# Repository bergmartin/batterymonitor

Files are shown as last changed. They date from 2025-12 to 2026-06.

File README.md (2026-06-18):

# ESP32 Battery Voltage Monitor

A PlatformIO project for monitoring 12V battery voltage using an ESP32 microcontroller with **ultra-low power consumption** through deep sleep mode.

## 🌟 Key Features

- **Ultra-Low Power:** Deep sleep mode with only 0.12-0.23 mA average draw (99.8% power reduction!)
- **Long Battery Life:** Monitor can run for years on the battery it's monitoring
- **MQTT Integration:** Publish readings to MQTT broker for remote monitoring (Home Assistant, Node-RED, etc.)
- **OLED Display:** SH1106 128x64 display shows battery voltage, percentage, status, and WiFi signal strength
- Real-time 12V battery voltage monitoring
- Support for **Lead-Acid** and **LiFePO4** battery types
- Battery type configured at build time
- Battery percentage calculation with type-specific thresholds
- Battery status indicators (FULL, GOOD, LOW_BATTERY, CRITICAL, DEAD)
- Visual battery level display with progress bar
- WiFi signal strength indicator
- Low battery warnings
- Averaged ADC readings for accuracy
- RTC memory for persistent data across sleep cycles
- **3D Printable Enclosure** for professional deployment

## ⚡ Power Consumption

| Mode | Current Draw | Battery Life (100Ah) |
|---|---|---|
| **Deep Sleep (default)** | 0.12-0.23 mA | **50-95 years** 🎉 |
| Continuous monitoring | 80-160 mA | 26-52 days |

**Deep sleep mode draws less power than the battery loses naturally!**

See [DEEP_SLEEP.md](doc/DEEP_SLEEP.md) for detailed power analysis.

## Hardware Requirements

### Components
- ESP32 development board
- 12V battery
- 100kΩ resistor (R1)
- 22kΩ resistor (R2)
- SH1106 OLED Display (128x64, I2C) - optional but recommended
- Connecting wires

### Circuit Diagram

```
12V Battery (+) ----[100kΩ]----+----[22kΩ]---- GND
                               |
                          GPIO34 (ADC)
                          ESP32
```

### Voltage Divider Explanation

The ESP32 ADC can only read voltages up to 3.3V. To safely measure a 12V battery (and up to 14.6V for LiFePO4), we use a voltage divider:

- **R1** (100kΩ) + **R2** (22kΩ) creates a 5.55:1 ratio
- 12V battery voltage becomes ~2.16V at the ADC pin
- Formula: `V_ADC = V_Battery × (R2 / (R1 + R2))`
- Result: `V_ADC = 12V × (22kΩ / 122kΩ) = 2.16V`

## Wiring Instructions

1. **Connect Voltage Divider:**
   - Solder 100kΩ resistor (R1) to battery positive terminal
   - Connect 22kΩ resistor (R2) between the junction and GND
   - Connect junction point to GPIO34 on ESP32

2. **Ground Connection:**
   - Connect battery negative terminal to ESP32 GND

3. **Power ESP32:**
   - Power the ESP32 via USB or separate power supply
   - **Important:** Do NOT power ESP32 directly from the 12V battery without a voltage regulator

## Software Setup

### Installation

1. Install [PlatformIO](https://platformio.org/)
2. Clone or download this project
3. Open the project in VS Code with PlatformIO extension

### MQTT Configuration (Optional)

To enable remote monitoring via MQTT:

1. **Configure WiFi credentials:**
   ```bash
   cd include/
   cp wifi_credentials.h.example wifi_credentials.h
   # Edit wifi_credentials.h with your WiFi SSID and password
   ```

2. **Configure MQTT broker:**
   ```bash
   cp mqtt_credentials.h.example mqtt_credentials.h
   # Edit mqtt_credentials.h with your MQTT broker details
   ```

3. **See [MQTT.md](doc/MQTT.md) for complete MQTT setup guide**, including:
   - MQTT broker options (Mosquitto, CloudMQTT, Home Assistant)
   - Topic structure and JSON format
   - Home Assistant integration
   - Testing and troubleshooting

### Build and Upload

**Default (Lead-Acid battery):**
```bash
# Build the project
pio run

# Upload to ESP32
pio run --target upload

# Monitor serial output
pio device monitor
```

**For LiFePO4 battery:**
```bash
# Build for LiFePO4
pio run -e esp32dev -D BATTERY_TYPE=BATTERY_TYPE_LIFEPO4

# Upload to ESP32
pio run -e esp32dev -D BATTERY_TYPE=BATTERY_TYPE_LIFEPO4 --target upload

# Monitor serial output
pio device monitor
```

**Alternative: Edit platformio.ini**

Change the build flag in the default `[env:esp32dev]` section:
```ini
build_flags = 
  -D BATTERY_TYPE=BATTERY_TYPE_LIFEPO4  ; Options: BATTERY_TYPE_LEAD_ACID or BATTERY_TYPE_LIFEPO4
```

Or use PlatformIO IDE buttons in VS Code.

## Testing

The project includes comprehensive unit tests for all battery monitoring logic.

### Run Tests

**Test Lead-Acid configuration:**
```bash
pio test -e esp32dev
```

**Test LiFePO4 configuration:**
```bash
pio test -e esp32dev -D BATTERY_TYPE=BATTERY_TYPE_LIFEPO4
```

**Test both configurations:**
```bash
pio test
```

The tests cover:
- Battery percentage calculations
- Battery status determination
- ADC to voltage conversion
- Voltage divider safety
- Edge cases and boundary conditions

See `test/README.md` for detailed testing documentation.

## Configuration

### Battery Type Selection

The project supports two battery types, configured at **build time**:

**Option 1: Use the default environment with build flag**
- `esp32dev` with default `BATTERY_TYPE_LEAD_ACID` build flag
- `esp32dev` with `-D BATTERY_TYPE=BATTERY_TYPE_LIFEPO4` build flag for LiFePO4

**Option 2: Edit the default environment**

In `platformio.ini`, modify the build_flags:
```ini
[env:esp32dev]
build_flags = 
  -D BATTERY_TYPE=LEAD_ACID  ; or LIFEPO4
```

### Voltage Thresholds

The voltage thresholds are automatically set based on battery type:

**Lead-Acid (12V):**
- Full: 12.7V
- Nominal: 12.4V (75%)
- Low: 12.0V (25%)
- Critical: 11.8V
- Minimum: 10.5V

**LiFePO4 (12V nominal, 4S configuration):**
- Full: 14.6V
- Nominal: 13.2V (75%)
- Low: 12.8V (25%)
- Critical: 12.0V
- Minimum: 10.0V

### Other Adjustable Parameters

You can adjust these parameters in `lib/BatteryMonitor/battery_config.h` (in the `Config` namespace):

```cpp
constexpr int BATTERY_ADC_PIN = 34;           // ADC pin (GPIO34)
constexpr float VOLTAGE_DIVIDER_RATIO = 5.545;  // Adjust if using different resistors
constexpr unsigned long READING_INTERVAL_MS = 10000;  // Reading interval (active mode, 10 seconds)
constexpr uint64_t DEEP_SLEEP_INTERVAL_US = 3600000000ULL;  // Deep sleep interval (1 hour)
```

### For Different Resistor Values

If you use different resistors, calculate the voltage divider ratio:

```
VOLTAGE_DIVIDER_RATIO = (R1 + R2) / R2
```

Example:
- R1 = 100kΩ, R2 = 33kΩ → Ratio = 4.03
- R1 = 20kΩ, R2 = 10kΩ → Ratio = 3.0

## Serial Output Example

**Lead-Acid Battery:**
```
=================================
ESP32 Battery Voltage Monitor
=================================
Battery Type: Lead-Acid
Voltage Range: 10.5V - 12.7V

─────────────────────────────────
Battery Voltage: 12.45 V
Battery Level:   88.6 %
Status:          GOOD
Battery: [████████░░]
```

**LiFePO4 Battery:**
```
=================================
ESP32 Battery Voltage Monitor
=================================
Battery Type: LiFePO4
Voltage Range: 10.0V - 14.6V

─────────────────────────────────
Battery Voltage: 13.84 V
Battery Level:   83.5 %
Status:          GOOD
Battery: [████████░░]
```

## Battery Voltage Guidelines

The project automatically configures voltage thresholds based on your battery type selection.

### Lead-Acid Batteries (12V)
- **12.7V** - Fully charged (100%)
- **12.4V** - 75% charged
- **12.2V** - 50% charged
- **12.0V** - 25% charged
- **11.8V** - Discharged (should recharge)
- **10.5V** - Minimum safe voltage

### LiFePO4 Batteries (12V nominal, 4S configuration)
- **14.6V** - Fully charged (100%) - 4 × 3.65V
- **13.6V** - 90% charged
- **13.2V** - 75% charged
- **13.0V** - 50% charged
- **12.8V** - 25% charged
- **12.0V** - Discharged (should recharge)
- **10.0V** - Minimum safe voltage - 4 × 2.5V

**Note:** LiFePO4 batteries have a flatter discharge curve than lead-acid, maintaining voltage better under load.

## Safety Notes

⚠️ **Important Safety Information:**

1. **Never exceed ADC input voltage:** Ensure your voltage divider outputs max 3.0V
2. **Double-check connections:** Incorrect wiring can damage your ESP32
3. **Use proper resistor wattage:** 1/4W resistors are typically sufficient
4. **Battery polarity:** Connect positive to R1, negative to GND
5. **Isolated ground:** If powering ESP32 separately, ensure common ground with battery

## Calibration

For more accurate readings, you can calibrate the system:

1. Measure actual battery voltage with a multimeter
2. Compare with ESP32 reading
3. Adjust the `VOLTAGE_DIVIDER_RATIO` constant if needed
4. The ADC may have slight variations; fine-tune the ratio for accuracy

## Troubleshooting

**Reading shows 0V:**
- Check voltage divider connections
- Verify GPIO34 is connected to the junction point
- Check resistor values

**Reading too high/low:**
- Verify resistor values (use multimeter)
- Recalculate voltage divider ratio
- Check for loose connections

**Unstable readings:**
- Increase SAMPLES count for more averaging
- Add a small capacitor (0.1µF) across R2
- Check for electromagnetic interference

**MQTT not connecting:**
- See [MQTT.md](doc/MQTT.md) troubleshooting section
- Verify WiFi credentials in `include/wifi_credentials.h`
- Check MQTT broker is accessible and credentials are correct
- Test broker with mosquitto-clients: `mosquitto_sub -h broker -t "#"`

## Documentation

- **[WIRING.md](doc/WIRING.md)** - Detailed wiring instructions with buck converter setup
- **[DISPLAY.md](doc/DISPLAY.md)** - SH1106 OLED display wiring and configuration
- **[DEEP_SLEEP.md](doc/DEEP_SLEEP.md)** - Deep sleep implementation and power analysis
- **[MQTT.md](doc/MQTT.md)** - MQTT setup, configuration, and integration guide
- **[OTA.md](doc/OTA.md)** - Over-the-Air update setup and usage
- **[REFACTORING.md](doc/REFACTORING.md)** - Code structure and refactoring documentation
- **[AGENTS.md](doc/AGENTS.md)** - AI assistant context and best practices
- **[test/README.md](test/README.md)** - Testing framework and test documentation
- **[enclosure/README.md](enclosure/README.md)** - 3D printable enclosure guide

## License

MIT License - Feel free to modify and use in your projects.

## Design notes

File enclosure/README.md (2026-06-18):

# 3D Printable Enclosure

This directory contains files for creating a 3D printable enclosure for the ESP32 Battery Monitor.

## Files

- `battery_monitor_bottom.scad` - Bottom enclosure part (with mounting posts)
- `battery_monitor_lid.scad` - Lid part (with ventilation)
- `battery_monitor_enclosure.scad` - Combined design file (legacy, optional)
- `README.md` - This documentation

## Quick Start

### Option 1: Use OpenSCAD (Recommended)

1. **Install OpenSCAD** (free): https://openscad.org/

2. **Generate Bottom Part:**
   - Open `battery_monitor_bottom.scad`
   - Press F5 to preview
   - Press F6 to render
   - File > Export > Export as STL
   - Save as `battery_monitor_bottom.stl`

3. **Generate Lid Part:**
   - Open `battery_monitor_lid.scad`
   - Press F5 to preview
   - Press F6 to render
   - File > Export > Export as STL
   - Save as `battery_monitor_lid.stl`

4. **Customize** dimensions if needed (edit parameters at top of both files)
   - **Important:** Keep dimensions consistent between both files!

### Option 2: Download Pre-made STL Files

STL files are not included in the repository (they're large). Generate them using OpenSCAD or request them.

### Option 3: Use Online CAD Tools

Import the specifications below into:
- **Tinkercad** (https://tinkercad.com) - Web-based, beginner-friendly
- **Fusion 360** (free for hobbyists)
- **FreeCAD** (free, open source)

## Enclosure Specifications

### Dimensions
- **Outer:** 100mm × 70mm × 40mm (L×W×H)
- **Inner:** 95mm × 65mm × 37.5mm
- **Wall thickness:** 2.5mm
- **Corner radius:** 3mm (rounded edges)

### Features
- ESP32 mounting posts with M3 screw holes (4 posts)
- Cable entry holes (8mm diameter)
- Ventilation slots in lid (6 slots)
- Mounting holes for external mounting (M3, in corners)
- Wire management clips
- LED indicator hole (5mm)
- Label area on bottom
- Snap-fit lip design

### ESP32 Board Support
- Fits standard ESP32 dev boards (51mm × 28mm)
- Adjustable post positions for other boards
- 5mm mounting post height
- 3mm clearance under board

## 3D Printing Settings

### Recommended Settings
```
Layer Height:        0.2mm
Shell Thickness:     3 perimeters (1.2mm)
Top/Bottom Layers:   4-5 layers
Infill:              20%
Infill Pattern:      Grid or Gyroid
Support:             Yes (for mounting posts)
Support Overhang:    45°
Bed Adhesion:        Brim (5mm)
Material:            PLA or PETG
Nozzle Temperature:  200-210°C (PLA), 230-240°C (PETG)
Bed Temperature:     60°C (PLA), 80°C (PETG)
Print Speed:         50mm/s
```

### Material Recommendations

| Material | Indoor Use | Outdoor Use | Temperature Range | Notes |
|---|---|---|---|---|
| **PLA** | ✅ Excellent | ❌ Not recommended | 5-40°C | Easy to print, rigid |
| **PETG** | ✅ Excellent | ✅ Good | -20-60°C | More durable, flexible |
| **ABS** | ✅ Good | ✅ Excellent | -40-80°C | Requires heated enclosure |
| **ASA** | ✅ Good | ✅ Excellent | -40-80°C | UV resistant, like ABS |

**For automotive/outdoor:** Use PETG or ASA  
**For indoor/desktop:** PLA is fine

### Print Time & Material
- **Bottom part:** ~1.5-2 hours, ~25g material
- **Lid part:** ~45-60 minutes, ~15g material
- **Total:** ~2.5-3 hours, ~40g material (~$0.80 in filament)

## Assembly Instructions

### Required Hardware
- 4× M3 × 6mm screws (ESP32 mounting)
- 4× M3 × 10mm screws (lid mounting, optional)
- 4× M3 × 20mm screws + nuts (external mounting, optional)

### Step-by-Step Assembly

1. **Print Parts**
   - Print bottom and lid separately
   - Remove supports carefully from mounting posts
   - Clean any stringing or artifacts

2. **Post-Processing**
   - Test M3 screws in mounting post holes
   - If tight, use 2.5mm drill bit to clear holes
   - Sand any rough edges if desired

3. **Mount ESP32**
   - Place ESP32 dev board on mounting posts
   - Align mounting holes
   - Secure with 4× M3 × 6mm screws
   - Don't overtighten (can crack plastic)

4. **Connect Wiring**
   - Thread wires through cable entry holes
   - Use wire management clips to secure
   - Connect all components as per [WIRING.md](../doc/WIRING.md)
   - Ensure wires don't interfere with lid

5. **Test Before Closing**
   - Power on and verify functionality
   - Check serial output
   - Verify all connections

6. **Install Lid**
   - Position lid on top
   - Ensure lip fits inside box properly
   - If using screws, install 4× M3 × 10mm screws
   - Alternative: friction fit or use adhesive

7. **External Mounting (Optional)**
   - Use M3 × 20mm screws through bottom corner holes
   - Mount to wall, vehicle, or enclosure
   - Ensure ventilation slots are not blocked

## Customization Guide

### Adjust Dimensions

Edit these parameters in the `.scad` file:

```openscad
// Make it bigger
box_length = 120;  // Default: 100
box_width = 80;    // Default: 70
box_height = 50;   // Default: 40

// For different ESP32 boards
esp32_length = 55;  // Measure your board
esp32_width = 30;   // Measure your board

// Thicker walls for outdoor use
wall_thickness = 3.5;  // Default: 2.5

// Larger cable holes for thicker wires
cable_hole_diameter = 10;  // Default: 8
```

### Add Features

**Add mounting holes:**
```openscad
translate([x, y, -1])
    cylinder(d=3.2, h=wall_thickness+2, $fn=32);
```

**Add text label:**
```openscad
translate([x, y, wall_thickness/2])
    linear_extrude(height=wall_thickness/2 + 0.5)
    text("Your Text", size=5, halign="center");
```

**More ventilation:**
Change the loop counter:
```openscad
for(i = [0:9])  // Default: [0:5] for 6 slots
```

## Troubleshooting

### Print Issues

**Posts break off:**
- Increase wall thickness around posts
- Add more perimeters (4-5 instead of 3)
- Reduce print speed to 40mm/s
- Ensure supports are used

**Lid doesn't fit:**
- Increase `lid_gap` parameter (try 0.4 or 0.5)
- Check if printer is calibrated (dimensional accuracy)
- Sand the lip edges slightly

**Warping:**
- Use bed adhesion (brim or raft)
- Ensure bed is level
- Increase bed temperature by 5-10°C
- Reduce part cooling for first layers

**Layer adhesion poor:**
- Increase nozzle temperature by 5°C
- Slow down print speed
- Check filament for moisture

### Fit Issues

**ESP32 doesn't fit:**
- Measure your actual board dimensions
- Adjust `esp32_length` and `esp32_width` parameters
- Re-export and print

**Screw holes too tight:**
- Use 2.5mm or 3mm drill bit to clean holes
- Increase `mounting_hole_diameter` by 0.2mm
- Re-export and print

**Cables don't fit:**
- Increase `cable_hole_diameter`
- Use file or drill to enlarge existing holes
- Add additional cable holes in design

## Design Modifications

### Seal for Outdoor Use

Add gasket groove in lid:
```openscad
// In enclosure_lid() module, add:
translate([wall_thickness + 2, wall_thickness + 2, wall_thickness])
    difference() {
        rounded_box(inner_length - 4, inner_width - 4, 1.5, corner_radius-1);
        translate([1, 1, -1])
            rounded_box(inner_length - 6, inner_width - 6, 3, corner_radius-1.5);
    }
```

Use 2mm foam weather stripping as gasket.

### DIN Rail Mount

Add DIN rail clip to bottom:
```openscad
// See: https://www.thingiverse.com/thing:xxxx for clip design
// Or use commercial DIN rail adapters
```

### Wall Mount Flanges

Add mounting tabs to sides:
```openscad
// On sides of box
translate([0, box_width/2 - 10, box_height/4])
    cube([wall_thickness*2, 20, 2]);
```

## Alternative Enclosures

If 3D printing isn't available:

### Commercial Enclosures
- **Hammond 1591XXCSBK** (100×50×25mm, polycarbonate)
- **Bud Industries NBF-32026** (ABS project box)
- **Polycase WC-40** (IP65 rated)

Drill holes as needed for cables and mounting.

### DIY Alternatives
- Plastic food container (cheap, waterproof)
- Junction box from hardware store
- Mint tin (Altoids) for temporary/small builds
- 3D printing service (Shapeways, Sculpteo) if no printer

## Files & Downloads

### OpenSCAD File
`battery_monitor_enclosure.scad` - Fully parametric design

### Export Your Own STL
1. Open `.scad` file in OpenSCAD
2. Customize parameters
3. F6 to render
4. Export as STL

### Sharing
If you create improved versions:
- Fork the repository
- Submit pull request with your design
- Share on Thingiverse/Printables with link back

## License

This enclosure design is released under the same license as the main project (see main LICENSE file).

Free to use, modify, and distribute. Attribution appreciated!

## Credits

Design specifications based on:
- Standard ESP32 dev board dimensions
- Common battery monitor requirements
- 3D printing best practices

## Support

For issues with the enclosure design:
1. Check OpenSCAD syntax (F5 preview shows errors)
2. Verify dimensions match your components
3. Test print one part first
4. Open GitHub issue if problems persist

For 3D printing help:
- r/3Dprinting on Reddit
- OpenSCAD forums
- Your printer manufacturer support

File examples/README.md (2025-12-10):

# BatteryMonitor Library Examples

This directory contains example sketches demonstrating different uses of the BatteryMonitor library.

## Available Examples

### 1. Basic Monitoring (main.cpp)
The default application in `src/main.cpp` demonstrates basic usage:
- Simple setup and initialization
- Periodic voltage readings
- Automatic status display
- Built-in warnings

**Use this when:** You want simple, out-of-the-box battery monitoring.

### 2. Advanced Monitoring (advanced_monitoring.cpp)
Demonstrates advanced features:
- Data logging and statistics
- Custom alert thresholds
- Running averages
- Min/max voltage tracking
- Session statistics

**Use this when:** You need data analysis, custom alerts, or historical tracking.

## Using an Example

### Method 1: Copy to main.cpp
```bash
cp examples/advanced_monitoring.cpp src/main.cpp
pio run --target upload
```

### Method 2: Reference in your own code
Include the library and use the examples as reference:

```cpp
#include "battery_monitor.h"

BatteryMonitor monitor;

void setup() {
  Serial.begin(115200);
  monitor.begin();
  monitor.printStartupInfo();
}

void loop() {
  BatteryReading reading = monitor.readBattery();
  monitor.printReading(reading);
  delay(2000);
}
```

## Key Concepts

### BatteryReading Structure
```cpp
struct BatteryReading {
  float voltage;          // Battery voltage in volts
  float percentage;       // Battery level 0-100%
  BatteryStatus status;   // FULL, GOOD, LOW_BATTERY, CRITICAL, DEAD
  unsigned long timestamp; // millis() when reading was taken
};
```

### BatteryStatus Enum
```cpp
enum class BatteryStatus {
  FULL,        // >= VOLTAGE_FULL
  GOOD,        // >= VOLTAGE_NOMINAL
  LOW_BATTERY, // >= VOLTAGE_LOW_THRESHOLD
  CRITICAL,    // >= VOLTAGE_CRITICAL
  DEAD         // < VOLTAGE_CRITICAL
};
```

### Static Helper Functions
```cpp
// Calculate percentage from voltage
float percent = BatteryMonitor::calculatePercentage(12.5);

// Determine status from voltage
BatteryStatus status = BatteryMonitor::determineStatus(12.5);

// Convert status to string
const char* str = BatteryMonitor::statusToString(status);

// Convert ADC reading to voltage
float voltage = BatteryMonitor::adcToVoltage(3500);
```

## Configuration

All examples use the configuration from `battery_config.h`. To modify:

1. **Change reading interval:**
   ```cpp
   // In your code, not in config
   const unsigned long MY_INTERVAL = 5000;  // 5 seconds
   ```

2. **Adjust sample count:**
   Modify `Config::SAMPLE_COUNT` in `battery_config.h`

3. **Change battery type:**
   Set in `platformio.ini`:
   ```ini
   build_flags = -D BATTERY_TYPE=LIFEPO4
   ```

## Custom Alerts Example

```cpp
void checkVoltageAlert(const BatteryReading& reading) {
  const float WARNING_VOLTAGE = 11.8;
  
  if (reading.voltage < WARNING_VOLTAGE) {
    // Send notification, trigger relay, etc.
    digitalWrite(LED_PIN, HIGH);
  }
}
```

## Data Logging Example

```cpp
void logToSD(const BatteryReading& reading) {
  File logFile = SD.open("/battery.log", FILE_APPEND);
  logFile.print(reading.timestamp);
  logFile.print(",");
  logFile.print(reading.voltage, 3);
  logFile.print(",");
  logFile.println(reading.percentage, 1);
  logFile.close();
}
```

## Tips

1. **Sampling:** More samples = more accurate but slower readings
2. **Timing:** Use non-blocking code in loop() for responsive monitoring
3. **Filtering:** Consider implementing a moving average for smoother readings
4. **Calibration:** Use a multimeter to verify voltage readings and adjust if needed
5. **Temperature:** Battery voltage varies with temperature - consider compensation

## Troubleshooting

**Readings seem noisy:**
- Increase `Config::SAMPLE_COUNT`
- Add capacitor across voltage divider output
- Check for loose connections

**Voltage reads too high/low:**
- Verify voltage divider resistor values
- Check `Config::VOLTAGE_DIVIDER_RATIO`
- Measure actual resistor values with multimeter

**Status doesn't match expected:**
- Adjust voltage thresholds in `battery_config.h`
- Different battery types have different voltage curves

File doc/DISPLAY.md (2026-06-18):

# SH1106 OLED Display Wiring

## Display Specifications
- **Model**: SH1106 OLED Display
- **Resolution**: 128x64 pixels
- **Interface**: I2C
- **Operating Voltage**: 3.3V - 5V
- **I2C Address**: 0x3C (default)

## Wiring Connections

### Default Pin Configuration
| SH1106 Pin | ESP32 Pin | Description |
|---|---|---|
| VCC | 3.3V | Power supply (3.3V or 5V) |
| GND | GND | Ground |
| SCL | GPIO 22 | I2C Clock (default) |
| SDA | GPIO 21 | I2C Data (default) |

### Wiring Diagram
```
ESP32                    SH1106 Display
┌─────────────┐         ┌──────────────┐
│             │         │              │
│     3.3V ───┼─────────┼─── VCC       │
│      GND ───┼─────────┼─── GND       │
│  GPIO 22 ───┼─────────┼─── SCL       │
│  GPIO 21 ───┼─────────┼─── SDA       │
│             │         │              │
└─────────────┘         └──────────────┘
```

## Custom Pin Configuration

If you need to use different I2C pins, you can modify the pin definitions in the code:

### Option 1: Modify DisplayConfig in display_manager.h
```cpp
namespace DisplayConfig {
    const uint8_t I2C_SDA = 21;  // Change to your SDA pin
    const uint8_t I2C_SCL = 22;  // Change to your SCL pin
    const uint8_t I2C_ADDRESS = 0x3C;
    const unsigned long UPDATE_INTERVAL = 1000;
}
```

### Option 2: Pass custom pins during initialization
```cpp
// In main.cpp setup()
display.begin(/* sda */ 21, /* scl */ 22);
```

## Complete Battery Monitor Wiring

When combined with the battery monitor circuit:

```
12V Battery
    │
    ├─── R1 (100kΩ) ─── GPIO 34 (ADC) ─── R2 (22kΩ) ─── GND
    │
    └─── Power Supply (12V to 5V converter)
              │
              └─── ESP32 5V/3.3V Input
                         │
                         ├─── SH1106 VCC
                         ├─── SH1106 GND
                         ├─── SH1106 SCL (GPIO 22)
                         └─── SH1106 SDA (GPIO 21)
```

## Display Features

The display shows:
- **Battery Voltage**: Large display of current voltage
- **Battery Percentage**: Visual progress bar and numeric value
- **Battery Status**: Current state (FULL, GOOD, LOW, CRITICAL, DEAD)
- **WiFi Status**: Connection state and signal strength
- **WiFi RSSI**: Signal strength in dBm with visual indicator
- **Boot Information**: Boot count on startup
- **OTA Status**: Update progress messages
- **Sleep Screen**: Countdown before deep sleep

## Troubleshooting

### Display not working?
1. **Check I2C address**: Some SH1106 displays use 0x3D instead of 0x3C
   - Scan for I2C devices with an I2C scanner sketch
   - Update `I2C_ADDRESS` in `display_manager.h` if different

2. **Check wiring**: Ensure SDA and SCL are not swapped

3. **Check power**: Ensure the display is getting proper 3.3V or 5V

4. **Pull-up resistors**: Most SH1106 modules have built-in pull-ups, but if needed:
   - Add 4.7kΩ resistors from SDA to 3.3V
   - Add 4.7kΩ resistors from SCL to 3.3V

### Serial Monitor Messages
- **Success**: "SH1106 Display initialized"
- **Failure**: "Failed to initialize SH1106 display!"

## Power Consumption Impact

The SH1106 OLED display adds approximately:
- **Active**: 20-30 mA (screen on)
- **Deep Sleep**: Display is powered off during sleep mode

Total power budget:
- **Active with display**: ~100-190 mA (~5-7 seconds)
- **Deep Sleep**: ~0.01 mA (display off, 4 hours)
- **Average impact**: Minimal, still <1 mA average

## Notes

- The display automatically turns off during deep sleep to save power
- Display updates are throttled to 1 second intervals to reduce CPU load
- Battery and WiFi icons provide quick visual status
- All text and graphics are rendered using the U8g2 library

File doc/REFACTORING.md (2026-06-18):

# Code Refactoring Summary

## Overview
Successfully refactored the ESP32 Battery Monitor project from procedural code to a well-structured, object-oriented architecture.

## Key Improvements

### 1. **Object-Oriented Design**
- **Before:** Procedural functions scattered across files
- **After:** `BatteryMonitor` class with clear responsibilities
- **Benefits:** Better encapsulation, reusability, and testability

### 2. **Configuration Management**
Created `battery_config.h` with structured configuration:
```cpp
namespace Config {
  // Hardware settings
  constexpr int BATTERY_ADC_PIN = 34;
  constexpr float VOLTAGE_DIVIDER_RATIO = 5.545;
  
  // Battery-specific thresholds
  namespace Voltage {
    constexpr float FULL = 12.7;
    constexpr float NOMINAL = 12.4;
    // ...
  }
}
```

**Benefits:**
- All configuration in one place
- Compile-time constants (constexpr)
- Type safety
- Easy to modify

### 3. **Type Safety with Enums**
```cpp
enum class BatteryStatus {
  FULL, GOOD, LOW_BATTERY, CRITICAL, DEAD
};
```

**Benefits:**
- Type-safe status codes
- No magic strings
- Better IDE autocomplete

### 4. **Structured Data**
```cpp
struct BatteryReading {
  float voltage;
  float percentage;
  BatteryStatus status;
  unsigned long timestamp;
};
```

**Benefits:**
- All related data together
- Easier to pass around
- Enables data logging
- Timestamp for historical tracking

### 5. **Simplified Main Application**
**Before (114 lines):**
- Mixed concerns
- Display logic in main
- ADC configuration in setup
- Repeated code

**After (47 lines):**
```cpp
BatteryMonitor monitor;

void setup() {
  Serial.begin(Config::SERIAL_BAUD_RATE);
  monitor.begin();
  monitor.printStartupInfo();
}

void loop() {
  BatteryReading reading = monitor.readBattery();
  monitor.printReading(reading);
  delay(Config::READING_INTERVAL_MS);
}
```

**Benefits:**
- Clean, readable code
- Single responsibility
- Easy to understand
- Less error-prone

### 6. **Better Separation of Concerns**

| File | Responsibility |
|---|---|
| `battery_config.h` | Hardware config, thresholds |
| `battery_monitor.h` | Class interface, types |
| `battery_monitor.cpp` | Implementation |
| `main.cpp` | Application logic |

### 7. **Static Helper Methods**
```cpp
// Can be used without instance
float percent = BatteryMonitor::calculatePercentage(12.5);
BatteryStatus status = BatteryMonitor::determineStatus(12.5);
const char* str = BatteryMonitor::statusToString(status);
```

**Benefits:**
- Utility functions accessible anywhere
- No instance needed for pure calculations
- Useful for testing and external use

### 8. **Backward Compatibility**
Maintained legacy functions for tests:
```cpp
// Still works for existing tests
float calculateBatteryPercentage(float voltage);
String getBatteryStatus(float voltage);
```

**Benefits:**
- Existing tests continue to pass
- Gradual migration path
- No breaking changes

## Code Metrics

### Complexity Reduction
- **Main.cpp:** 114 → 47 lines (59% reduction)
- **Cyclomatic complexity:** Reduced through method extraction
- **Code duplication:** Eliminated

### Maintainability Improvements
- **Configuration changes:** 1 file instead of 3
- **Adding new battery type:** Modify 1 section
- **Adding new features:** Clear extension points

## New Features Enabled

### 1. **Data Logging**
```cpp
BatteryReading reading = monitor.readBattery();
logToSD(reading.timestamp, reading.voltage);
```

### 2. **Custom Alerts**
```cpp
if (reading.status == BatteryStatus::CRITICAL) {
  sendNotification();
}
```

### 3. **Statistics Tracking**
```cpp
minVoltage = min(minVoltage, reading.voltage);
avgVoltage = (avgVoltage + reading.voltage) / 2;
```

### 4. **Multiple Monitors**
```cpp
BatteryMonitor mainBattery;
BatteryMonitor backupBattery;
```

## Quality Improvements

### 1. **Const Correctness**
- Used `constexpr` for compile-time constants
- Const member functions where appropriate
- Const references to avoid copies

### 2. **Naming Conventions**
- Clear, descriptive names
- Consistent naming scheme
- Avoided abbreviations

### 3. **Comments & Documentation**
- Header comments explaining purpose
- Inline comments for complex logic
- Example code provided

### 4. **Error Handling**
- Voltage clamping
- Bounds checking
- Safe defaults

## Testing

### Verification
✅ All existing tests pass
✅ Compiles for Lead-Acid configuration
✅ Compiles for LiFePO4 configuration
✅ No warnings or errors
✅ Binary size unchanged (~277KB)

### Test Coverage
- 32+ unit tests
- Both battery types tested
- Boundary conditions covered
- Edge cases handled

## Examples Provided

### 1. **Basic Example** (src/main.cpp)
Simple monitoring with auto-display

### 2. **Advanced Example** (examples/advanced_monitoring.cpp)
- Data logging
- Statistics tracking
- Custom alerts
- Session management

## Performance

### Memory Usage
- **Stack:** Minimal increase (struct on stack)
- **Heap:** No dynamic allocation
- **Flash:** ~1KB increase (methods + strings)
- **RAM:** 21640 bytes (unchanged)

### Speed
- No performance degradation
- Compile-time resolution of constants
- Inlining of small methods

## Migration Guide

### For Existing Users
```cpp
// Old way
float voltage = readBatteryVoltage();
displayBatteryInfo(voltage);

// New way
BatteryReading reading = monitor.readBattery();
monitor.printReading(reading);
```

### For New Features
```cpp
// Create monitor
BatteryMonitor monitor;

// Initialize
monitor.begin();

// Read and use data
BatteryReading reading = monitor.readBattery();
if (reading.status == BatteryStatus::LOW_BATTERY) {
  // Handle low battery
}
```

## Future Enhancements Enabled

This refactoring makes these additions easier:

1. **Web Interface:** Easy to serialize BatteryReading to JSON
2. **MQTT Publishing:** Structured data ready for transmission
3. **Multiple Batteries:** Instantiate multiple monitors
4. **Calibration:** Add calibration methods to class
5. **History Buffer:** Add circular buffer to class
6. **Filtering:** Add Kalman filter or moving average
7. **Alarms:** Add threshold monitoring with callbacks

## Conclusion

The refactoring successfully transformed a working but procedural codebase into a well-structured, object-oriented library that:
- Is easier to maintain and extend
- Provides better encapsulation
- Enables new features
- Maintains backward compatibility
- Improves code readability
- Reduces complexity

**Status:** ✅ Complete, tested, and committed to repository.

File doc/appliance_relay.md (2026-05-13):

# Appliance Relay Management Implementation Plan

## Objective
Implement an appliance relay management feature controlled via MQTT. The appliance will remain off if the battery voltage falls below a dedicated threshold. The relay state will be maintained during the ESP32's deep sleep mode using RTC GPIO hold capabilities.

## Key Files & Context
- `lib/BatteryMonitor/battery_config.h`: Will house new constants for the appliance relay GPIO pin (must be RTC-capable) and the low-voltage cutoff threshold.
- `lib/ConfigManager/config_manager.h`: Needs to store the intended relay state (ON/OFF) in NVS to ensure state recovery after deep sleep wakeup.
- `lib/NetworkManager/network_manager.h` & `network_manager.cpp`: Will handle subscribing to the MQTT command topic (`battery/monitor/appliance/set`), publishing the current state (`.../appliance/state`), and publishing the Home Assistant Discovery configuration for a Switch entity.
- `src/main.cpp`: Will orchestrate reading the battery voltage, evaluating it against the cutoff threshold, applying the intended state to the GPIO pin, and enabling `rtc_gpio_hold_en` before entering deep sleep.

## Implementation Steps

### 1. Configuration Additions
In `lib/BatteryMonitor/battery_config.h`:
- Define `APPLIANCE_RELAY_PIN` (e.g., GPIO 26 or 27 - must be an RTC GPIO).
- Define `APPLIANCE_CUTOFF_VOLTAGE` within the respective battery type namespaces (e.g., 12.2V for Lead-Acid, 12.8V for LiFePO4).

### 2. State Persistence
In `lib/ConfigManager/config_manager.h`:
- Add a boolean variable `applianceTargetState` (default `false`).
- Update `begin()`, `saveConfig()`, and `resetToDefaults()` to persist this variable in NVS under the key `"appl_state"`.

### 3. MQTT and Home Assistant Integration
In `lib/NetworkManager/network_manager.h` & `network_manager.cpp`:
- **Subscription:** Subscribe to the appliance command topic (`.../appliance/set`).
- **Callback:** In `mqttCallback`, intercept commands sent to the appliance topic (e.g., "ON", "OFF", "1", "0", "true", "false"). Update `config.applianceTargetState` and call `config.saveConfig()`.
- **Publish State:** In `publishReading()`, evaluate the *actual* appliance state (which may be OFF despite the target state if the battery is too low) and publish it to `.../appliance/state`.
- **HA Discovery:** In `publishHomeAssistantDiscovery()`, add a JSON configuration payload for a Home Assistant Switch entity targeting the appliance topics.

### 4. Hardware Control & Deep Sleep Retention
In `src/main.cpp`:
- Include `driver/rtc_io.h` and `driver/gpio.h`.
- Disable GPIO hold on boot using `gpio_hold_dis()` / `rtc_gpio_hold_dis()` so the pin can be reconfigured.
- Initialize `APPLIANCE_RELAY_PIN` as an `OUTPUT`.
- After calling `monitor.readBattery()`, evaluate the rule:
  `bool actualState = config.applianceTargetState && (reading.voltage >= Config::Voltage::APPLIANCE_CUTOFF_VOLTAGE);`
- Write `actualState` to the `APPLIANCE_RELAY_PIN`.
- In `enterDeepSleep()`, right before `esp_deep_sleep_start()`, enable GPIO hold for the relay pin using `rtc_gpio_hold_en(APPLIANCE_RELAY_PIN)` to maintain the relay state while the processor sleeps.

## Verification & Testing
- **MQTT Command:** Send an "ON" command via MQTT and verify the intended state is saved and applied.
- **Deep Sleep:** Trigger deep sleep and verify (using a multimeter on the assigned pin) that the pin retains its HIGH or LOW state during sleep.
- **Voltage Cutoff:** Simulate a low battery voltage below `APPLIANCE_CUTOFF_VOLTAGE` and verify the relay turns OFF, regardless of the MQTT-commanded target state.
- **HA Discovery:** Verify a new Switch entity appears in Home Assistant and correctly controls the target state.
\ No newline at end of file

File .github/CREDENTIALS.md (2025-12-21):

# Credential Management for GitHub Actions

## Understanding How Credentials Work

### GitHub-Built Binaries
The firmware binaries built by GitHub Actions contain **placeholder credentials** by default. This is intentional and correct for most use cases.

### Why Placeholder Credentials Are OK

**OTA updates don't need real credentials because:**
1. OTA only updates the firmware code
2. Credentials are stored separately in ESP32 flash memory
3. Your existing WiFi/MQTT credentials are preserved during OTA

**Example workflow:**
```
Initial Setup (USB) → Device has your credentials
     ↓
OTA Update (MQTT) → Firmware updates, credentials stay
     ↓
Device reboots → Uses existing credentials + new firmware
```

## Setup Options

### Option 1: Placeholder Credentials (Recommended)

**Best for:** Multiple users, open-source projects, when devices have different credentials

**How it works:**
1. GitHub builds firmware with placeholder values
2. Each user configures credentials locally
3. First upload via USB with real credentials
4. Future OTA updates preserve those credentials

**Steps:**
```bash
# 1. Clone repository
git clone https://github.com/YOUR_USERNAME/batterymonitor.git
cd batterymonitor

# 2. Configure YOUR credentials locally
cp include/wifi_credentials.h.example include/wifi_credentials.h
cp include/mqtt_credentials.h.example include/mqtt_credentials.h

# Edit files with your actual credentials
nano include/wifi_credentials.h
nano include/mqtt_credentials.h

# 3. Build and upload (USB) - includes YOUR credentials
pio run -e esp32dev -t upload

# 4. Future updates via OTA - credentials preserved
mosquitto_pub -h BROKER -t "battery/monitor/ota" -m "batterymonitor.bin"
```

**GitHub release binaries contain:** Placeholder credentials  
**Your device contains:** Your real credentials (from step 3)  
**OTA updates:** Don't touch credentials

### Option 2: GitHub Secrets (For Single Deployment)

**Best for:** Single installation, all devices use same credentials, private repository

**How it works:**
1. Store credentials as GitHub Secrets
2. GitHub builds firmware with your actual credentials
3. Download and upload directly - no local configuration needed

**Setup:**

#### A. Add Secrets to GitHub
1. Go to repository **Settings** → **Secrets and variables** → **Actions**
2. Click **New repository secret**
3. Add each secret:
   - `WIFI_SSID` = `your-wifi-name`
   - `WIFI_PASSWORD` = `your-wifi-password`
   - `MQTT_SERVER` = `mqtt.example.com`
   - `MQTT_PORT` = `1883`
   - `MQTT_USER` = `mqtt-user`
   - `MQTT_PASSWORD` = `mqtt-password`
   - `MQTT_CLIENT_ID` = `battery-monitor`

#### B. Update Workflow File
Edit `.github/workflows/release.yml` and uncomment the "Option B" section:

```yaml
# Uncomment this section:
cat > include/wifi_credentials.h << EOF
#ifndef WIFI_CREDENTIALS_H
#define WIFI_CREDENTIALS_H

#define WIFI_SSID "${{ secrets.WIFI_SSID }}"
#define WIFI_PASSWORD "${{ secrets.WIFI_PASSWORD }}"

#endif
EOF
```

(Comment out Option A - the placeholder section)

#### C. Use the Release
```bash
# 1. Download firmware from GitHub release
wget https://github.com/USER/REPO/releases/download/v1.0.0/firmware.bin

# 2. Upload directly - no credential configuration needed!
pio run -e esp32dev -t upload

# 3. OTA updates work immediately
mosquitto_pub -h BROKER -t "battery/monitor/ota" -m "firmware.bin"
```

**⚠️ Security Warning:**
- Anyone with access to your release binaries can extract credentials
- Only use for private repositories
- Don't share release binaries publicly

## Which Option Should You Use?

| Scenario | Best Option | Why |
|---|---|-----|
| Open source project | Option 1 (Placeholder) | Users configure their own credentials |
| Multiple locations | Option 1 (Placeholder) | Each site has different WiFi/MQTT |
| Personal project | Either | Your choice |
| Same credentials everywhere | Option 2 (Secrets) | Convenient, pre-configured |
| Public repository | Option 1 (Placeholder) | Never expose real credentials |

## FAQ

### Q: Why don't GitHub binaries connect to WiFi?
**A:** They contain placeholder credentials. This is intentional - configure locally before first upload.

### Q: Will OTA updates lose my credentials?
**A:** No! OTA only updates code, not credentials. Your WiFi/MQTT settings are preserved.

### Q: Can I change credentials via OTA?
**A:** No. Credentials must be changed locally and re-uploaded via USB.

### Q: What if I have multiple devices?
**A:** With Option 1, each device can have different credentials configured during initial USB upload.

### Q: Are my credentials secure?
**A:** 
- **Option 1:** Credentials never leave your computer (most secure)
- **Option 2:** Credentials stored in GitHub Secrets (encrypted at rest)
- Both options: Credentials compiled into firmware (not easily readable)

## Troubleshooting

### Device won't connect after OTA update
```
Problem: Using GitHub binary on fresh device
Solution: Configure credentials locally first, upload via USB
```

### Want to change WiFi network
```
Problem: Need to update credentials
Solution: 
1. Edit wifi_credentials.h locally
2. Upload via USB (not OTA)
3. Device now uses new credentials
```

### Multiple devices, different networks
```
Problem: Each location has different WiFi
Solution: Use Option 1
- Configure credentials locally for each device
- Upload each device via USB with its specific credentials
- All devices can use same OTA firmware updates
```

## Example: Complete Setup

```bash
# Day 1: Initial setup (USB required)
git clone https://github.com/myuser/batterymonitor.git
cd batterymonitor
cp include/*.h.example include/
nano include/wifi_credentials.h  # Add your WiFi
nano include/mqtt_credentials.h  # Add your MQTT
pio run -e esp32dev -t upload  # Upload via USB

# Day 30: Firmware update available (no USB needed!)
# Device wakes up, checks MQTT, receives update command
mosquitto_pub -h mqtt.home.local \
  -t "battery/monitor/ota" \
  -m "firmware.bin"

# Device downloads from GitHub, installs, reboots
# Credentials unchanged, firmware updated ✓
```

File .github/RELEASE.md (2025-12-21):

# GitHub Actions Release Workflow

This repository is configured to automatically build and release firmware binaries when you push a version tag.

## How It Works

1. **Push a tag** starting with `v` (e.g., `v1.0.0`)
2. **GitHub Actions** automatically:
   - Builds both Lead-Acid and LiFePO4 firmware variants
   - Creates firmware files with version numbers
   - Generates SHA256 checksums
   - Creates a GitHub release
   - Uploads all binaries to the release

## Creating a Release

### Step 1: Commit your changes
```bash
git add .
git commit -m "Your commit message"
git push
```

### Step 2: Create and push a version tag
```bash
# Create a new version tag
git tag v1.0.0

# Or with annotation (recommended)
git tag -a v1.0.0 -m "Release version 1.0.0"

# Push the tag to GitHub
git push origin v1.0.0
```

### Step 3: Wait for the build
- Go to your repository on GitHub
- Click on **Actions** tab
- Watch the workflow run (takes ~2-5 minutes)
- When complete, check the **Releases** section

## Files Generated

Each release includes:
- `batterymonitor-leadacid-v1.0.0.bin` - Lead-Acid variant (with version)
- `batterymonitor-leadacid.bin` - Lead-Acid variant (generic name)
- `batterymonitor-lifepo4-v1.0.0.bin` - LiFePO4 variant (with version)
- `batterymonitor-lifepo4.bin` - LiFePO4 variant (generic name)
- `checksums.txt` - SHA256 checksums for verification

## Using "latest" for OTA Updates

The workflow creates both versioned and generic filenames. This allows you to:

### Option 1: Use specific version URLs
```ini
; In platformio.ini
-D OTA_BASE_URL='"https://github.com/USER/REPO/releases/download/v1.0.0/"'
```

### Option 2: Use "latest" for automatic updates (Recommended)
```ini
; In platformio.ini
-D OTA_BASE_URL='"https://github.com/USER/REPO/releases/download/"'
```

Then trigger with:
```bash
mosquitto_pub -h BROKER -t "battery/monitor/ota" -m "batterymonitor-leadacid.bin"
```

## Credential Files

The workflow creates placeholder credential files for building. **Users must configure their own credentials** before uploading to their devices:

1. Copy example files:
   ```bash
   cp include/wifi_credentials.h.example include/wifi_credentials.h
   cp include/mqtt_credentials.h.example include/mqtt_credentials.h
   ```

2. Edit with your actual credentials

3. Build and upload locally:
   ```bash
   pio run -e esp32dev -t upload
   ```

## Versioning Guidelines

Follow [Semantic Versioning](https://semver.org/):
- `v1.0.0` - Major.Minor.Patch
- `v1.0.1` - Bug fixes
- `v1.1.0` - New features (backward compatible)
- `v2.0.0` - Breaking changes

## Troubleshooting

### Workflow fails to build
- Check the Actions tab for error details
- Ensure `platformio.ini` is valid
- Verify all source files compile locally first

### Release not created
- Make sure tag starts with `v`
- Check repository has Actions enabled
- Verify you have push access to the repository

### Wrong battery type
Make sure to specify the correct firmware file:
- Lead-Acid batteries: `batterymonitor-leadacid.bin`
- LiFePO4 batteries: `batterymonitor-lifepo4.bin`

## Manual Release (if needed)

If you prefer not to use GitHub Actions:

```bash
# Build locally (default: Lead-Acid)
pio run -e esp32dev

# Build for LiFePO4
pio run -e esp32dev -D BATTERY_TYPE=BATTERY_TYPE_LIFEPO4

# Create release manually on GitHub
# Upload .pio/build/esp32dev/firmware.bin
```

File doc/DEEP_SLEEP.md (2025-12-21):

# Deep Sleep Power Optimization

## Configuration Changes

### Reading Interval
- **Before:** Every 2 seconds
- **After:** Every 1 hour (3600 seconds)

### Power Mode
- **Before:** Always active
- **After:** Deep sleep between readings

## Power Consumption Comparison

### Original Configuration (Active Mode)
```
Active current: 80-160 mA
Duty cycle: 100% (always on)
Average current: 80-160 mA
Power @ 12V: 0.96-1.92 W
Daily consumption: 1.92-3.84 Ah
```

**Battery Life (100 Ah battery):**
- Best case: 26 days
- Worst case: 52 days

### New Configuration (Deep Sleep Mode)
```
Active current: 80-160 mA (for ~5 seconds)
Deep sleep current: 0.01 mA (10 µA)
Duty cycle: 0.14% active, 99.86% sleep

Calculation:
- Active time per hour: 5 seconds
- Sleep time per hour: 3595 seconds
- Average = (80mA × 5s + 0.01mA × 3595s) / 3600s
- Average current: 0.12-0.23 mA
```

**Power @ 12V:** 1.4-2.8 mW (milliwatts!)

**Daily consumption:** 2.9-5.6 mAh (0.0029-0.0056 Ah)

**Battery Life (100 Ah battery):**
- Best case: **94.2 years** (low current: 0.121 mA)
- Worst case: **49.1 years** (high current: 0.232 mA)

## Improvement Summary

| Metric | Before | After | Improvement |
|---|---|---|---|
| Average Current | 80-160 mA | 0.12-0.23 mA | **99.8% reduction** |
| Average Power | 0.96-1.92 W | 1.4-2.8 mW | **99.85% reduction** |
| Daily Usage | 1.92-3.84 Ah | 2.9-5.6 mAh | **700x less** |
| Battery Life | 26-52 days | 49-94 years | **700x longer** |

## Features

### RTC Memory Persistence
Data preserved across deep sleep cycles:
- Boot count tracking
- Last voltage reading
- Historical data (can be expanded)

### Smart Wake-up
- Timer-based wakeup every hour
- Configurable interval
- Fast boot and reading (~5 seconds)

### Serial Output
Each boot displays:
```
╔═════════════════════════════════╗
║  ESP32 Battery Monitor (Deep Sleep) ║
╚═════════════════════════════════╝
Boot count: 42
Wakeup caused by timer
Last voltage: 12.45 V

─────────────────────────────────
Battery Voltage: 12.43 V
Battery Level:   87.3 %
Status:          GOOD
Battery: [████████░░]

Time awake: 4235 ms
─────────────────────────────────
Entering deep sleep mode...
Next reading in: 3600 seconds
Power consumption: ~10 µA
─────────────────────────────────
```

## Configuration Options

### Disable Deep Sleep (testing/debugging)
In `battery_config.h`:
```cpp
constexpr bool ENABLE_DEEP_SLEEP = false;
```

### Change Reading Interval
```cpp
// 1 hour (default)
constexpr uint64_t DEEP_SLEEP_INTERVAL_US = 3600000000ULL;

// 30 minutes
constexpr uint64_t DEEP_SLEEP_INTERVAL_US = 1800000000ULL;

// 2 hours
constexpr uint64_t DEEP_SLEEP_INTERVAL_US = 7200000000ULL;

// 6 hours
constexpr uint64_t DEEP_SLEEP_INTERVAL_US = 21600000000ULL;
```

### Adjust Awake Time
```cpp
constexpr int AWAKE_TIME_MS = 5000;  // 5 seconds (default)
constexpr int AWAKE_TIME_MS = 10000; // 10 seconds (more time for serial)
```

## Real-World Battery Life Examples

### 12V 7Ah SLA Battery (alarm systems)
- Before: 1.8-3.6 days
- **After: 3.5-7 years** ✅

### 12V 35Ah Car Battery (backup power)
- Before: 9-18 days
- **After: 17-35 years** ✅

### 12V 100Ah Deep Cycle (solar/RV)
- Before: 26-52 days
- **After: 50-95 years** ✅

### 12V 200Ah LiFePO4 (off-grid)
- Before: 52-104 days
- **After: 100-190 years** ✅

## Practical Considerations

### Why Not Infinite?
The battery itself has:
- Self-discharge: 2-5% per month (lead-acid)
- Self-discharge: 1-3% per month (LiFePO4)
- This is 600-15,000x more than the monitor draws!

### Actual Limiting Factor
**Battery self-discharge**, not the monitor.

The monitor now uses less power than the battery loses naturally!

## Use Cases Enabled

### Long-Term Monitoring
- Storage battery health checks
- Seasonal equipment (boats, RVs)
- Emergency backup systems
- Solar system monitoring

### Remote Installations
- Off-grid locations
- No external power needed
- Battery lasts for years

### Data Logging
With RTC memory, can track:
- Min/max voltages
- Charge cycles
- Degradation over time

## Technical Details

### ESP32 Deep Sleep
- CPU powered off
- Most RAM powered off
- RTC and ULP co-processor active
- Wake sources: timer, GPIO, touchpad, ULP

### Current Breakdown (Deep Sleep)
- RTC timer: ~5 µA
- RTC memory: ~2 µA
- ULP co-processor: ~3 µA
- Total: ~10 µA (0.01 mA)

### Voltage Divider Current
Even with voltage divider always on:
- 12V / 40kΩ = 0.3 mA
- Still negligible compared to original active draw
- Could use higher resistor values for even less

## Recommended Settings

### For Maximum Battery Life
```cpp
constexpr uint64_t DEEP_SLEEP_INTERVAL_US = 21600000000ULL; // 6 hours
constexpr int SAMPLE_COUNT = 5;  // Faster reading
```

### For Frequent Monitoring
```cpp
constexpr uint64_t DEEP_SLEEP_INTERVAL_US = 900000000ULL; // 15 minutes
constexpr int SAMPLE_COUNT = 10; // Standard accuracy
```

### For Development/Testing
```cpp
constexpr bool ENABLE_DEEP_SLEEP = false;
constexpr unsigned long READING_INTERVAL_MS = 5000; // 5 seconds
```

## Migration from Previous Version

The deep sleep version is **fully backward compatible** in the library. Only the main application changed.

To switch back to continuous monitoring:
```cpp
// In battery_config.h
constexpr bool ENABLE_DEEP_SLEEP = false;
```

## Conclusion

Deep sleep mode transforms the battery monitor from a **power-hungry** device (80-160 mA) to an **ultra-low-power** device (0.12-0.23 mA), making it practical for:
- Long-term deployment
- Battery-powered systems
- Remote monitoring
- Storage applications

The monitor now draws **less power than the battery loses naturally**, making it essentially **"free"** in terms of battery impact! 🎉

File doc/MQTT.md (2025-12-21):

# MQTT Integration Guide

This document explains how to configure and use the MQTT functionality for publishing battery monitoring data.

## Overview

The battery monitor publishes readings to an MQTT broker every 1 hour (configurable). This enables:
- Remote monitoring via MQTT clients (Home Assistant, Node-RED, etc.)
- Historical data logging
- Alerting and automation based on battery status
- Integration with smart home systems

## MQTT Topics

All messages are published to topics under the base: `battery/monitor/`

### Individual Topics

- `battery/monitor/voltage` - Battery voltage (e.g., "12.45")
- `battery/monitor/percentage` - Battery percentage (e.g., "85.2")
- `battery/monitor/status` - Battery status ("FULL", "GOOD", "LOW", "CRITICAL")
- `battery/monitor/type` - Battery type ("Lead-Acid" or "LiFePO4")
- `battery/monitor/boot_count` - Number of times ESP32 has woken up

### JSON Topic

- `battery/monitor/json` - All data in JSON format:
  ```json
  {
    "voltage": 12.45,
    "percentage": 85.2,
    "status": "GOOD",
    "type": "Lead-Acid",
    "boot": 42,
    "rssi": -65
  }
  ```

### Configuration Topics

- `battery/monitor/config/battery_type` (QoS 1)
  - Payload: `leadacid` or `lifepo4` (case-insensitive)
  - Effect: Updates battery chemistry thresholds and persists to NVS.
  - Acknowledgement: Device publishes current type to `{hostname}_battery_type/state`.

## Configuration

### 1. Set Up Credentials

Create credential files from the templates:

```bash
cd include/
cp wifi_credentials.h.example wifi_credentials.h
cp mqtt_credentials.h.example mqtt_credentials.h
```

### 2. Configure WiFi

Edit `include/wifi_credentials.h`:

```cpp
#define WIFI_SSID "YourWiFiNetwork"
#define WIFI_PASSWORD "YourWiFiPassword"
```

### 3. Configure MQTT Broker

Edit `include/mqtt_credentials.h`:

```cpp
#define MQTT_SERVER "mqtt.example.com"  // Broker hostname or IP
#define MQTT_PORT 1883                   // Standard MQTT port
#define MQTT_USER "username"             // Leave "" if no auth
#define MQTT_PASSWORD "password"         // Leave "" if no auth
#define MQTT_CLIENT_ID "esp32-battery-monitor"
```

### 4. Build and Upload

```bash
pio run -e esp32dev --target upload
# or for LiFePO4
pio run -e esp32dev -D BATTERY_TYPE=BATTERY_TYPE_LIFEPO4 --target upload
```

## MQTT Broker Options

### Self-Hosted (Recommended for local use)

**Mosquitto** - Lightweight, open-source MQTT broker

Installation:
```bash
# Ubuntu/Debian
sudo apt install mosquitto mosquitto-clients

# macOS
brew install mosquitto
```

Start broker:
```bash
mosquitto -v
```

Configuration in `mqtt_credentials.h`:
```cpp
#define MQTT_SERVER "192.168.1.100"  // Your server IP
#define MQTT_PORT 1883
#define MQTT_USER ""
#define MQTT_PASSWORD ""
#define MQTT_CLIENT_ID "esp32-battery-monitor"
```

### Cloud MQTT Services

1. **CloudMQTT** (https://www.cloudmqtt.com/)
   - Free tier available
   - Easy setup
   - Global CDN

2. **HiveMQ Cloud** (https://www.hivemq.com/mqtt-cloud-broker/)
   - Free tier: 100 connections
   - Good documentation
   - TLS support

3. **AWS IoT Core** (https://aws.amazon.com/iot-core/)
   - Scalable
   - Integrates with AWS services
   - Requires certificates

### Public Test Broker (Testing only)

**test.mosquitto.org** - Public MQTT broker for testing

⚠️ **WARNING**: No security, data is public!

```cpp
#define MQTT_SERVER "test.mosquitto.org"
#define MQTT_PORT 1883
#define MQTT_USER ""
#define MQTT_PASSWORD ""
#define MQTT_CLIENT_ID "esp32-battery-monitor-test"
```

## Testing MQTT

### Subscribe to Topics (Linux/macOS)

Install mosquitto-clients:
```bash
# Ubuntu/Debian
sudo apt install mosquitto-clients

# macOS
brew install mosquitto
```

Subscribe to all battery topics:
```bash
mosquitto_sub -h mqtt.example.com -t "battery/monitor/#" -v
```

Subscribe to JSON topic only:
```bash
mosquitto_sub -h mqtt.example.com -t "battery/monitor/json"
```

With authentication:
```bash
mosquitto_sub -h mqtt.example.com -u username -P password -t "battery/monitor/#"
```

### MQTT Client Apps

1. **MQTT Explorer** (https://mqtt-explorer.com/)
   - GUI application for Windows/macOS/Linux
   - Visual topic hierarchy
   - Real-time updates

2. **MQTT.fx** (https://mqttfx.jensd.de/)
   - Desktop client
   - Good for testing

3. **Home Assistant**
   - Automatic MQTT discovery
   - Built-in dashboards
   - Automation support

## Home Assistant Integration

### Auto-Discovery Configuration

Add to Home Assistant `configuration.yaml`:

```yaml
mqtt:
  sensor:
    - name: "Battery Voltage"
      state_topic: "battery/monitor/voltage"
      unit_of_measurement: "V"
      device_class: voltage
      state_class: measurement
      
    - name: "Battery Percentage"
      state_topic: "battery/monitor/percentage"
      unit_of_measurement: "%"
      device_class: battery
      state_class: measurement
      
    - name: "Battery Status"
      state_topic: "battery/monitor/status"
      icon: mdi:battery
```

### Automation Example

```yaml
automation:
  - alias: "Battery Low Alert"
    trigger:
      - platform: mqtt
        topic: "battery/monitor/status"
        payload: "LOW"
    action:
      - service: notify.mobile_app
        data:
          message: "Battery is low! Voltage: {{ states('sensor.battery_voltage') }}V"
```

## Power Consumption

With MQTT enabled:
- **Awake time**: ~10-15 seconds (WiFi + MQTT connection + publish)
- **Active current**: ~80-160 mA
- **Deep sleep**: ~0.01 mA
- **Average consumption**: ~0.3-0.5 mA (with 1-hour intervals)

WiFi connection adds ~5-8 seconds to wake time.

## Troubleshooting

### WiFi Won't Connect

1. Check credentials in `wifi_credentials.h`
2. Verify WiFi signal strength at ESP32 location
3. Check 2.4GHz network (ESP32 doesn't support 5GHz)
4. Increase `WIFI_TIMEOUT_MS` in `battery_config.h`

Serial output:
```
Connecting to WiFi...... Failed!
```

### MQTT Won't Connect

1. Verify broker is running: `mosquitto -v`
2. Check broker IP/hostname in `mqtt_credentials.h`
3. Test broker with mosquitto_pub: `mosquitto_pub -h mqtt.example.com -t test -m "hello"`
4. Verify firewall allows port 1883
5. Check MQTT credentials (username/password)

Serial output:
```
Connecting to MQTT broker..... Failed!
```

### No Data Published

1. Check serial monitor for error messages
2. Verify topics with `mosquitto_sub -h mqtt.example.com -t "#" -v`
3. Check retained message flag
4. Increase `MQTT_TIMEOUT_MS` in `battery_config.h`

### Memory Issues

If ESP32 runs out of memory with MQTT enabled:
1. Reduce `SAMPLE_COUNT` in `battery_config.h`
2. Disable serial debug output
3. Use shorter MQTT_CLIENT_ID

## Customization

### Change Base Topic

Edit in `lib/BatteryMonitor/battery_config.h`:

```cpp
constexpr char MQTT_TOPIC_BASE[] = "home/garage/battery";
```

Results in topics like:
- `home/garage/battery/voltage`
- `home/garage/battery/json`

### Adjust Timeouts

Edit in `lib/BatteryMonitor/battery_config.h`:

```cpp
constexpr unsigned long WIFI_TIMEOUT_MS = 10000;  // 10 seconds (default)
constexpr unsigned long MQTT_TIMEOUT_MS = 10000;  // 10 seconds
```

### QoS and Retained Messages

Modify in `src/main.cpp` (publishToMQTT function):

```cpp
// QoS 0, not retained
mqttClient.publish(topic, value, false);

// QoS 1, retained
mqttClient.publish(topic, value, 1, true);
```

## Security Considerations

1. **Never commit credentials**: The `.gitignore` protects credential files
2. **Use authentication**: Set MQTT_USER and MQTT_PASSWORD
3. **Use TLS**: Change MQTT_PORT to 8883 and add TLS support
4. **Restrict topics**: Configure broker ACLs
5. **Local network**: Keep MQTT broker on local network if possible

## Performance Tips

1. **Connection time**: WiFi connection is the slowest part (~5-8 seconds)
2. **Retained messages**: Use retained flag so clients get last value immediately
3. **JSON vs individual**: JSON is more efficient for multiple subscribers
4. **QoS 0**: Fastest, no acknowledgment (use for non-critical data)
5. **Keep awake time short**: Disconnect immediately after publishing

## Additional Resources

- MQTT Protocol: https://mqtt.org/
- Mosquitto Documentation: https://mosquitto.org/documentation/
- Home Assistant MQTT: https://www.home-assistant.io/integrations/mqtt/
- PubSubClient Library: https://pubsubclient.knolleary.net/

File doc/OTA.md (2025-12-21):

# OTA (Over-The-Air) Updates

The battery monitor supports multiple OTA update methods with persistent trigger support and automatic version checking.

## Features

- ✅ **Persistent OTA Triggers** - MQTT OTA requests survive deep sleep and are processed on next boot
- ✅ **Automatic Version Checking** - Device can auto-check and install newer firmware versions  
- ✅ **Config-Based Updates** - Set target version via serial command or MQTT
- ✅ **Secure** - Base URL compiled into firmware, only filenames accepted via MQTT
- ✅ **Deep Sleep Compatible** - OTA triggers persist across sleep cycles

## Update Methods

### 1. Automatic Version-Based Updates (Recommended)

Set a target version and the device automatically downloads and installs it on next wake.

**Configure target version via serial:**
```bash
# Connect via serial and type:
otaver 1.0.2
save

# Device will check for and install v1.0.2 on next wake
```

**How it works:**
1. Set target version using `otaver` command
2. On every wake, device compares current version with target version
3. If target is newer, constructs URL: `BASE_URL/v1.0.2/firmware-leadacid.bin`
4. Downloads and installs firmware automatically
5. Version persists in NVS storage

**Enable/Disable:**
```cpp
// In battery_config.h
constexpr bool AUTO_CHECK_OTA = true;  // Set to false to disable
```

### 2. Manual MQTT-Triggered Updates

Immediately trigger an OTA update via MQTT. The trigger persists even if device is in deep sleep.

**Trigger with specific version:**
```bash
mosquitto_pub -h YOUR_MQTT_BROKER \
  -t "battery/monitor/ota" \
  -m "v1.0.2/firmware-leadacid.bin"
```

**Trigger ArduinoOTA mode:**
```bash
mosquitto_pub -h YOUR_MQTT_BROKER \
  -t "battery/monitor/ota" \
  -m "update"
```

**Deep Sleep Behavior:**
- If device is awake: OTA starts immediately
- If device is in deep sleep: Trigger is saved to persistent storage
- On next wake: Device checks for pending OTA and processes it before normal operation

### 3. ArduinoOTA (Network Upload)

Direct network upload using PlatformIO or Arduino IDE.

**Upload directly via network:**
```bash
# Configure platformio.ini with device IP:
# upload_protocol = espota
# upload_port = 192.168.1.XXX

pio run -t upload
```

**Or trigger OTA mode via MQTT first:**
```bash
mosquitto_pub -h YOUR_MQTT_BROKER \
  -t "battery/monitor/ota" \
  -m "update"
  
# Device waits 1 minute in OTA mode
# Then upload via PlatformIO
pio run -t upload
```

## Configuration

### Base URL Setup

Configure the base URL in `platformio.ini` (for GitHub releases):
```ini
build_flags = 
  -D BATTERY_TYPE=LEAD_ACID
  -D OTA_BASE_URL='"https://github.com/USERNAME/REPO/releases/download/"'
```

Or define in `ota_manager.h`:
```cpp
#ifndef OTA_BASE_URL
#define OTA_BASE_URL "https://github.com/USERNAME/REPO/releases/download/"
#endif
```

### Serial Commands

```bash
# Set target OTA version
otaver 1.0.2

# View current configuration (includes target version)
show

# Save configuration to NVS
save
```

### Firmware Naming Convention

Firmware files have simple names, with version in the URL path:
- Lead-Acid: `firmware-leadacid.bin` at URL path `v1.0.2/`
- LiFePO4: `firmware-lifepo4.bin` at URL path `v1.0.2/`
- Full URL: `BASE_URL/v1.0.2/firmware-leadacid.bin`

These are automatically generated by the GitHub Actions workflow.

## Release Workflow

### Creating a New Release

**1. Tag the version:**
```bash
git tag v1.0.2
git push origin v1.0.2
```

**2. GitHub Actions automatically:**
- Builds firmware with version embedded: `FIRMWARE_VERSION="1.0.2"`
- Creates firmware binaries:
  - `firmware-leadacid.bin`
  - `firmware-lifepo4.bin`
- Publishes to release at path: `releases/download/v1.0.2/`
- Creates GitHub release with all files

**3. Update devices:**

**Option A: Automatic (via serial config):**
```bash
# Connect via serial and set target version
otaver 1.0.2
save
# Device updates on next wake cycle
```

**Option B: Manual MQTT trigger:**
```bash
mosquitto_pub -h BROKER \
  -t "battery/monitor/ota" \
  -m "v1.0.2/firmware-leadacid.bin"
```

### Manual Build

Get firmware binary from PlatformIO build:

```bash
# Build the project
pio run

# Binary location:
.pio/build/esp32dev/firmware.bin
```

### Testing with Local Server

For local testing without GitHub:

1. **Configure local base URL:**
```ini
# In platformio.ini
-D OTA_BASE_URL='"http://192.168.1.100:8000/"'
```

2. **Serve the firmware:**
```bash
cd .pio/build/esp32dev/
python -m http.server 8000
```

3. **Trigger update:**
```bash
mosquitto_pub -h BROKER -t "battery/monitor/ota" -m "firmware.bin"
```

## Security Considerations

### Compile-Time Base URL
- Base URL is **hardcoded at compile time** and cannot be changed remotely
- Only filenames are accepted via MQTT (no paths, URLs, or special characters)
- Prevents injection of malicious firmware sources
- Must rebuild firmware to change base URL

### Input Validation
The device accepts:
- Path with version and filename: `v1.0.2/firmware-leadacid.bin`
- Simple filename for ArduinoOTA: `update` or empty

The device automatically rejects:
- Full URLs (containing `http://` or `https://`)
- Special characters (containing `:`)
- This prevents arbitrary firmware downloads

### HTTPS Recommendation
- Use HTTPS URLs for production (GitHub releases use HTTPS)
- HTTP acceptable for local testing only
- GitHub automatically provides secure TLS connections

### Password Protection

Optionally protect ArduinoOTA with a password in `ota_manager.cpp`:
```cpp
void OTAManager::setup() {
    ArduinoOTA.setHostname(config.mqttClientID.c_str());
    ArduinoOTA.setPassword("your_password");  // Uncomment and set password
    // ... rest of setup
}
```

## How Persistent OTA Works

### Storage Mechanism
OTA triggers are stored in ESP32's Preferences (NVS - Non-Volatile Storage):
- Survives deep sleep
- Survives power loss
- Survives reboots
- Persists until OTA completes or times out

### Boot Sequence
```
1. Device wakes from deep sleep
2. Check for pending OTA trigger in NVS
3. If pending:
   - Connect to WiFi
   - Download and install firmware
   - Clear OTA trigger on success/failure
4. Continue normal operation
```

### Automatic Version Check Flow
```
1. Device wakes from deep sleep
2. If AUTO_CHECK_OTA enabled:
   - Read otaTargetVersion from config
   - Compare with current FIRMWARE_VERSION
   - If target > current:
     - Construct path: v{target}/firmware-{type}.bin
     - Download and install
3. Continue normal operation
```

## Troubleshooting

### Update Fails
- Check base URL is correct in `platformio.ini` or `ota_manager.h`
- Verify filename matches exactly (case-sensitive)
- Ensure firmware file exists at `BASE_URL + filename`
- Check WiFi connection is stable
- Verify firmware is built for correct board
- Check serial output for detailed error messages

### Invalid Filename Error
If you see "ERROR: Invalid filename", the message contained:
- A colon (`:`)
- A full URL
- Send the path with version: `v1.0.2/firmware-leadacid.bin`

### Device Doesn't Respond to MQTT
- Verify MQTT topic matches: `battery/monitor/ota`
- Check device is connected to MQTT broker
- If in deep sleep: Trigger persists and will process on next wake
- Verify MQTT message was received (check broker logs)

### OTA Trigger Not Persisting
- Check serial output for "OTA trigger saved to persistent storage"
- Verify NVS is not full (unlikely with default settings)
- If cleared manually, use: `reset nvs` command restarts fresh

### Version Check Not Working
- Ensure AUTO_CHECK_OTA is true in battery_config.h
- Set target version: `otaver 1.0.2` and `save`
- Verify target version in config: `show` command
- Check serial output for version comparison logs

### Progress Monitoring
- Watch serial output during update
- HTTP updates show download progress percentage
- OTA timeout: 60 seconds for ArduinoOTA mode
- Check for "OTA trigger cleared" message on completion

## Power Considerations

During OTA updates, the device:
- Stays awake (80-160 mA current draw)
- ArduinoOTA mode: 60 seconds timeout
- HTTP update: ~30-60 seconds typical
- Returns to deep sleep after completion

**Power Budget:**
- Normal operation: ~0.1-0.3 mA average (99.9% in deep sleep)
- During OTA: ~100 mA for 30-60 seconds
- Minimal impact on battery life for infrequent updates

## Examples

### Complete Update Workflow

**1. Release new firmware:**
```bash
# Tag and push
git tag v1.0.3
git push origin v1.0.3

# GitHub Actions builds and releases automatically
```

**2. Update a single device (serial):**
```bash
# Connect via serial
otaver 1.0.3
save

# Device updates on next wake
```

**3. Update all devices (MQTT broadcast):**
```bash
# Option A: Set via MQTT to config (if implemented)
# Or use serial on each device

# Option B: Force immediate update
mosquitto_pub -h BROKER \
  -t "battery/monitor/ota" \
  -m "v1.0.3/firmware-leadacid.bin"
```

### Rollback to Previous Version

```bash
# Via serial
otaver 1.0.1
save

# Device downloads v1.0.1 on next wake
```

### Emergency Update (Device in Deep Sleep)

```bash
# Trigger via MQTT
mosquitto_pub -h BROKER \
  -t "battery/monitor/ota" \
  -m "v1.0.4/firmware-leadacid.bin"

# Trigger persists in NVS
# Processes automatically on next wake (up to 1 hour later)
```

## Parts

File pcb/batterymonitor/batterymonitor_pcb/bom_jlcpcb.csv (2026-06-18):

Comment | Designator | Footprint | LCSC Part #
10uF/25V | C1 | Capacitor_SMD:C_0805_2012Metric | C40894
22uF/10V | C2 | Capacitor_SMD:C_0805_2012Metric | C89572
100nF/10V | C3 | Capacitor_SMD:C_0805_2012Metric | C49678
12V_Input | J1 | TerminalBlock_TE-Connectivity:TerminalBlock_TE_282834-2_1x02_P2.54mm_Horizontal | C50993
100k | R1 | Resistor_SMD:R_0805_2012Metric | C149504
22k | R2 | Resistor_SMD:R_0805_2012Metric | C17560
AP63300 | U1 | Package_TO_SOT_SMD:TSOT-23-6 | C2158012
ESP32-WROOM-32U-N4 | U2 | RF_Module:ESP32-WROOM-32U | C328062
Conn_01x04_Pin | J2 | Connector_PinHeader_2.54mm:PinHeader_1x04_P2.54mm_Vertical | C124375
4.7uH | L1 | Inductor_SMD:L_0806_2012Metric | C98335
100nF/50V | C4 | Capacitor_SMD:C_0805_2012Metric | C49678
100k | R3 | Resistor_SMD:R_0805_2012Metric | C149504
32k | R4 | Resistor_SMD:R_0805_2012Metric | C182555
SS14 | D1 | Diode_SMD:D_SOD-123 | C169540
SS14 | D2 | Diode_SMD:D_SOD-123 | C169540
USB_C_Receptacle_HRO_TYPE-C-31-M-12 | J3 | Connector_USB:USB_C_Receptacle_HRO_TYPE-C-31-M-12 | C165948
CH340C | U3 | Package_SO:SOIC-16_3.9x9.9mm_P1.27mm | C84681
S8050 | Q1 | Package_TO_SOT_SMD:SOT-23 | C2146
S8050 | Q2 | Package_TO_SOT_SMD:SOT-23 | C2146
1k | R5 | Resistor_SMD:R_0805_2012Metric | C17513
1k | R6 | Resistor_SMD:R_0805_2012Metric | C17513
5.1k | R7 | Resistor_SMD:R_0805_2012Metric | C27834
5.1k | R8 | Resistor_SMD:R_0805_2012Metric | C27834
10k | R9 | Resistor_SMD:R_0805_2012Metric | C17414
10k | R10 | Resistor_SMD:R_0805_2012Metric | C17414
10k | R11 | Resistor_SMD:R_0805_2012Metric | C17414
100nF/10V | C5 | Capacitor_SMD:C_0805_2012Metric | C49678
DC_Jack_Female | J4 | Connector_BarrelJack:BarrelJack_Horizontal | C136605

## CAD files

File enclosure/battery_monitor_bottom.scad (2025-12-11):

/*
 * ESP32 Battery Monitor Enclosure - BOTTOM PART
 * 
 * OpenSCAD script to generate 3D printable enclosure bottom
 * 
 * To use:
 * 1. Install OpenSCAD (free): https://openscad.org/
 * 2. Open this file in OpenSCAD
 * 3. Press F5 to preview
 * 4. Press F6 to render
 * 5. File > Export > Export as STL
 * 
 * Print settings:
 * - Layer height: 0.2mm
 * - Infill: 20%
 * - Supports: Yes (for mounting posts)
 * - Material: PLA or PETG
 */

// ============================================================================
// Configuration Parameters (adjust as needed)
// ============================================================================

// Box dimensions (in mm)
box_length = 100;      // X dimension
box_width = 70;        // Y dimension
box_height = 40;       // Z dimension (total height)
wall_thickness = 2.5;  // Wall thickness

// ESP32 board dimensions (typical dev board)
esp32_length = 51;     // PCM board length
esp32_width = 28;      // PCM board width
esp32_height = 15;     // Including USB connector

// Component spacing
bottom_clearance = 3;  // Space under ESP32 for wiring
top_clearance = 10;    // Space above ESP32

// Mounting
mounting_hole_diameter = 3.2;  // M3 screw holes
mounting_post_diameter = 6;    // Posts for ESP32
mounting_post_height = 5;      // Height of mounting posts

// Cable management
cable_hole_diameter = 8;  // For wires entering box

// Rounded corners
corner_radius = 3;

// ============================================================================
// Calculated Values
// ============================================================================

inner_length = box_length - 2 * wall_thickness;
inner_width = box_width - 2 * wall_thickness;
inner_height = box_height - wall_thickness;

// ============================================================================
// Modules
// ============================================================================

// Rounded box module
module rounded_box(length, width, height, radius) {
    hull() {
        translate([radius, radius, 0])
            cylinder(r=radius, h=height, $fn=32);
        translate([length-radius, radius, 0])
            cylinder(r=radius, h=height, $fn=32);
        translate([radius, width-radius, 0])
            cylinder(r=radius, h=height, $fn=32);
        translate([length-radius, width-radius, 0])
            cylinder(r=radius, h=height, $fn=32);
    }
}

// Main box (bottom part)
module enclosure_bottom() {
    difference() {
        // Outer shell
        rounded_box(box_length, box_width, box_height/2 + wall_thickness, corner_radius);
        
        // Inner cavity
        translate([wall_thickness, wall_thickness, wall_thickness])
            rounded_box(inner_length, inner_width, box_height/2 + 1, corner_radius-0.5);
        
        // Cable entry holes
        // Bottom cable hole (for power)
        translate([box_length/2, wall_thickness/2, wall_thickness + 5])
            rotate([-90, 0, 0])
            cylinder(d=cable_hole_diameter, h=wall_thickness*2, $fn=32);
        
        // Side cable hole (optional for voltage divider)
        translate([wall_thickness/2, box_width/2, wall_thickness + 5])
            rotate([0, 90, 0])
            cylinder(d=cable_hole_diameter, h=wall_thickness*2, $fn=32);
        
        // Mounting holes in bottom (for external mounting)
        for(x = [10, box_length-10]) {
            for(y = [10, box_width-10]) {
                translate([x, y, -1])
                    cylinder(d=mounting_hole_diameter, h=wall_thickness+2, $fn=32);
            }
        }
        
        // Label area (recessed text placeholder)
        translate([box_length/2, box_width - 8, wall_thickness/2])
            linear_extrude(height=wall_thickness/2 + 0.5)
            text("Battery Monitor", size=5, halign="center", valign="center", font="Liberation Sans:style=Bold");
    }
    
    // ESP32 mounting posts
    post_offset_x = (box_length - esp32_length) / 2;
    post_offset_y = (box_width - esp32_width) / 2;
    
    for(x = [post_offset_x, post_offset_x + esp32_length - mounting_post_diameter]) {
        for(y = [post_offset_y, post_offset_y + esp32_width - mounting_post_diameter]) {
            translate([x + mounting_post_diameter/2, y + mounting_post_diameter/2, wall_thickness]) {
                difference() {
                    cylinder(d=mounting_post_diameter, h=mounting_post_height, $fn=32);
                    // Screw hole
                    translate([0, 0, -1])
                        cylinder(d=2.5, h=mounting_post_height+2, $fn=16);
                }
            }
        }
    }
    
    // Wire management clips
    translate([wall_thickness + 5, wall_thickness + 2, wall_thickness])
        cube([3, 2, 4]);
    translate([box_length - wall_thickness - 8, wall_thickness + 2, wall_thickness])
        cube([3, 2, 4]);
}

// ============================================================================
// Generate Bottom Part
// ============================================================================

enclosure_bottom();

// ============================================================================
// Print Instructions
// ============================================================================

/*
TO EXPORT STL FILE:
1. F6 to render (may take a few seconds)
2. File > Export > Export as STL
3. Save as: battery_monitor_bottom.stl

3D PRINTING SETTINGS:
- Layer height: 0.2mm
- Shell thickness: 3 perimeters (1.2mm)
- Infill: 20%
- Supports: Yes (for mounting posts)
- Bed adhesion: Brim recommended
- Material: PLA or PETG
- Print time: ~1.5-2 hours

POST-PROCESSING:
- Remove supports carefully from mounting posts
- Clean mounting post holes with 2.5mm drill bit if needed
- Test fit ESP32 board before final assembly
- Verify cable holes are clear and smooth

ASSEMBLY:
1. Insert ESP32 board into bottom part
2. Align mounting holes with posts
3. Secure with M3 x 6mm screws from bottom
4. Route wiring through cable holes
5. Test functionality before adding lid

CUSTOMIZATION:
Adjust parameters at top of file:
- box_length, box_width, box_height: Overall dimensions
- esp32_length, esp32_width: Match your board
- cable_hole_diameter: For your wire gauge
- mounting_post_height: For different ESP32 heights
*/

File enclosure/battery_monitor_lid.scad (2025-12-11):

/*
 * ESP32 Battery Monitor Enclosure - LID PART
 * 
 * OpenSCAD script to generate 3D printable enclosure lid
 * 
 * To use:
 * 1. Install OpenSCAD (free): https://openscad.org/
 * 2. Open this file in OpenSCAD
 * 3. Press F5 to preview
 * 4. Press F6 to render
 * 5. File > Export > Export as STL
 * 
 * Print settings:
 * - Layer height: 0.2mm
 * - Infill: 20%
 * - Supports: No
 * - Material: PLA or PETG
 */

// ============================================================================
// Configuration Parameters (adjust as needed)
// ============================================================================

// Box dimensions (in mm) - MUST MATCH BOTTOM PART
box_length = 100;      // X dimension
box_width = 70;        // Y dimension
box_height = 40;       // Z dimension (total height)
wall_thickness = 2.5;  // Wall thickness

// Lid
lid_lip_height = 3;    // Overlap between lid and box
lid_gap = 0.3;         // Clearance gap

// Ventilation
vent_slot_width = 2;
vent_slot_length = 20;
vent_slot_spacing = 4;

// Mounting
mounting_hole_diameter = 3.2;  // M3 screw holes

// Rounded corners
corner_radius = 3;

// ============================================================================
// Calculated Values
// ============================================================================

inner_length = box_length - 2 * wall_thickness;
inner_width = box_width - 2 * wall_thickness;

// ============================================================================
// Modules
// ============================================================================

// Rounded box module
module rounded_box(length, width, height, radius) {
    hull() {
        translate([radius, radius, 0])
            cylinder(r=radius, h=height, $fn=32);
        translate([length-radius, radius, 0])
            cylinder(r=radius, h=height, $fn=32);
        translate([radius, width-radius, 0])
            cylinder(r=radius, h=height, $fn=32);
        translate([length-radius, width-radius, 0])
            cylinder(r=radius, h=height, $fn=32);
    }
}

// Lid (top part)
module enclosure_lid() {
    difference() {
        union() {
            // Main lid
            rounded_box(box_length, box_width, wall_thickness, corner_radius);
            
            // Lip that fits inside box
            translate([wall_thickness + lid_gap, wall_thickness + lid_gap, wall_thickness])
                rounded_box(
                    inner_length - 2*lid_gap, 
                    inner_width - 2*lid_gap, 
                    lid_lip_height, 
                    corner_radius-1
                );
        }
        
        // Ventilation slots
        for(i = [0:5]) {
            translate([box_length/2 - 3*vent_slot_spacing + i*vent_slot_spacing, 
                      box_width/2 - vent_slot_length/2, 
                      -1])
                cube([vent_slot_width, vent_slot_length, wall_thickness+2]);
        }
        
        // LED indicator hole (if you add one)
        translate([box_length - 10, box_width - 10, -1])
            cylinder(d=5, h=wall_thickness+2, $fn=32);
        
        // Mounting screw holes for lid
        for(x = [10, box_length-10]) {
            for(y = [10, box_width-10]) {
                translate([x, y, -1])
                    cylinder(d=mounting_hole_diameter, h=wall_thickness+2, $fn=32);
                // Countersink
                translate([x, y, wall_thickness/2])
                    cylinder(d1=mounting_hole_diameter, d2=mounting_hole_diameter+2, h=wall_thickness/2+1, $fn=32);
            }
        }
    }
}

// ============================================================================
// Generate Lid Part
// ============================================================================

enclosure_lid();

// ============================================================================
// Print Instructions
// ============================================================================

/*
TO EXPORT STL FILE:
1. F6 to render (may take a few seconds)
2. File > Export > Export as STL
3. Save as: battery_monitor_lid.stl

3D PRINTING SETTINGS:
- Layer height: 0.2mm
- Shell thickness: 3 perimeters (1.2mm)
- Infill: 20%
- Supports: No (prints flat)
- Bed adhesion: Brim optional
- Material: PLA or PETG (match bottom part)
- Print time: ~1-1.5 hours

POST-PROCESSING:
- Remove any brim or support material
- Clean mounting screw holes if needed
- Verify ventilation slots are clear
- Test fit on bottom part before assembly

ASSEMBLY:
1. Ensure all components are installed in bottom part
2. Test functionality with lid open
3. Place lid on top of bottom part
4. Verify lip fits inside bottom part
5. Secure with M3 x 10mm screws through mounting holes (optional)
6. For permanent seal, can use small amount of adhesive

CUSTOMIZATION:
Adjust parameters at top of file:
- IMPORTANT: Dimensions must match bottom part!
- lid_gap: Increase for looser fit, decrease for tighter fit
- vent_slot_width/length: Adjust ventilation
- lid_lip_height: Change snap-fit depth
*/

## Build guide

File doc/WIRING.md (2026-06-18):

# ESP32 Battery Monitor - Wiring Guide

This guide describes how to connect and configure the electronic components for the Battery Monitor. There are two primary options to build this project:
1. **Option A: Breadboard / Prototyping Setup**: Using an off-the-shelf ESP32 development board, an external buck converter module (e.g., LM2596), and discrete resistors.
2. **Option B: Custom PCB Design**: Solder SMT components directly onto the custom PCB, featuring an integrated high-efficiency **AP63300 synchronous buck converter** (12V → 3.3V) and an on-board voltage divider.

---

## Option A: Breadboard / Prototyping Setup

### Prototyping Wiring Diagram
```
                    ┌─────────────────┐
12V Battery (+) ────┤ Buck Converter  │
                    │  (12V → 5V)     ├──── 5V ──→ ESP32 VIN
                    └─────────────────┘
                            │
                            └──────────────→ GND ──→ ESP32 GND
                                                      
12V Battery (+) ────[100kΩ R1]───┬────[22kΩ R2]──── GND
                                 │
                           GPIO34 (ESP32)

12V Battery (−) ───────────────────────────────────→ Common GND
```

### Option A Required Components
| Component | Specification | Quantity | Notes |
|---|---|---|---|
| ESP32 Development Board | NodeMCU or similar with GPIO34 | 1 | With built-in USB/Serial & 3.3V LDO |
| Buck Converter Module | LM2596 or similar, 12V→5V | 1 | Adjustable output recommended |
| Resistor R1 | 100kΩ, 1/4W or higher | 1 | For voltage divider (high side) |
| Resistor R2 | 22kΩ, 1/4W or higher | 1 | For voltage divider (low side) |
| Fuse | 1A, automotive blade type | 1 | Safety protection |
| Fuse Holder | Inline blade fuse holder | 1 | For easy replacement |

### Option A Step-by-Step Instructions

#### 1. Power Supply Circuit Setup:
* Connect the battery positive (+) terminal through the 1A fuse to the buck converter input (`IN+`).
* Connect the battery negative (-) terminal to the buck converter input (`IN-`).
* **Critical:** Use a multimeter to measure the output of the buck converter. Adjust the onboard potentiometer until the output reads exactly **5.0V** before connecting it to the ESP32.
* Connect the buck converter output (`OUT+`) to the ESP32 `VIN` (or `5V`) pin.
* Connect the buck converter output (`OUT-`) to the ESP32 `GND` pin.

#### 2. Voltage Divider Setup:
* Connect the battery positive (+) terminal to one end of the 100kΩ resistor ($R_1$).
* Connect the other end of $R_1$ to a junction point.
* Connect the junction point to the ESP32 analog input pin (**GPIO34**).
* Connect a 22kΩ resistor ($R_2$) between the junction point and the common `GND`.
* The divider divides the battery voltage down by a ratio of $5.545:1$ (safe $2.16\text{V}$ for $12\text{V}$ input, max $2.63\text{V}$ for fully-charged LiFePO4 battery at $14.6\text{V}$).

---

## Option B: Custom PCB Design (Recommended)

The custom PCB (located in the [pcb/](file:///home/martin/projects/batterymonitor/pcb) directory) integrates all power management, sensing, and display routing onto a single compact board.

### Custom PCB Architecture Block Diagram
```
                              Custom PCB (All-in-One)
                  ┌────────────────────────────────────────────────────────┐
                  │ 12V Battery Input (J1 Terminal / J4 DC Jack)            │
                  │        │                                               │
                  │        ├──→ [D1 SS14] ──┐                              │
                  │        │                ├──→ 12V Net ──→ [AP63300 Buck]│
                  │        └─→ [Divider]    │                  (12V→3.3V)  │
                  │                │        │                       │      │
                  │             GPIO34      │                       ▼      │
                  │                │        │                     3.3V     │
                  │                │        │                      │       │
                  │ USB-C (J3) ────┼─ [D2] ─┘                      │       │
                  │    │           │                               │       │
                  │    ├──→ [CH340C Bridge] ── [R5/R6] ── RXD0/TXD0 ───┤       │
                  │    │       │                                   │       │
                  │    │    [Q1/Q2 Auto-Reset] ─────────────────── EN/IO0  │
                  │    │                                           │       │
                  │    ▼                                           ▼       │
                  │ [R7/R8 CC Pull-downs]                 [ESP32-WROOM-32U]│
                  │                                                │       │
                  │                                                └─→ OLED│
                  └────────────────────────────────────────────────────────┘
```

### Integrated AP63300 Synchronous Buck Converter
Instead of using an external bulk module that regulates to 5V, the PCB integrates a **Diodes Inc. AP63300** synchronous buck converter (`U1`).
* **High Efficiency**: Operates at $>90\%$ efficiency, generating minimal heat compared to linear regulators (like the AMS1117 which wastes energy as heat).
* **Direct 3.3V Power**: Steps the battery's 12V input directly down to **3.3V**, powering the ESP32 module (`U2`) directly.
* **Low Noise (EMI)**: Features a frequency spread spectrum (FSS) clocking system operating at 500kHz to reduce electromagnetic interference.
* **Dual-Source Power OR-ing**: Two Schottky barrier diodes (`D1` and `D2`, SS14) form an OR-ing power selector at the buck converter input (`12V` net). This allows safe concurrent connection of the 12V battery raw input and USB-C VBUS (5V) without back-feeding or damage. The AP63300's wide input voltage range (down to 3.8V in LDO mode) enables it to regulate to 3.3V from either source.

#### AP63300 Supporting Passive Network
The PCB utilizes the following optimized component layout:
* **Inductor (`L1`)**: A $4.7\,\mu\text{H}$ Sunlord molded power inductor (`MPL2016S4R7MHT`, LCSC Part: `C98335`) in an 0806 package, selected for optimal switching performance.
* **Bootstrap Capacitor (`C4`)**: A $100\,\text{nF}$ 50V X7R ceramic capacitor (`C49678`) connected between the `SW` (Switching) and `BST` (Bootstrap) pins to drive the high-side MOSFET.
* **Feedback Network (`R3`, `R4`)**:
  * $R_3 = 100\,\text{k}\Omega$ 1% 0805 (`C149504`)
  * $R_4 = 32\,\text{k}\Omega$ 1% 0805 (`C182555`)
  * Based on the feedback reference voltage ($V_{\text{fb}} = 0.8\text{V}$), this resistor ratio delivers exactly $3.30\text{V}$ output:
    $$V_{\text{out}} = 0.8\text{V} \times \left(1 + \frac{R_3}{R_4}\right) = 0.8\text{V} \times \left(1 + \frac{100\,\text{k}\Omega}{32\,\text{k}\Omega}\right) = 3.30\text{V}$$
* **Input/Output Filtering (`C1`, `C2`)**:
  * Input capacitor $C_1$: $10\,\mu\text{F}$ 25V X5R ceramic capacitor (`C40894`) to handle voltage ripples.
  * Output capacitor $C_2$: $22\,\mu\text{F}$ 10V X5R ceramic capacitor (`C89572`) to stabilize the 3.3V rail.

### USB-C Programming & Auto-Reset Interface
To facilitate easy firmware updates and serial monitoring, the custom PCB includes an on-board USB-C receptacle (`J3`) and a **CH340C USB-to-UART bridge** (`U3`).
* **Auto-Reset Circuitry**: A transistor-based reset network (`Q1`, `Q2`, `R9`, `R10`) toggles the ESP32's `EN` and `GPIO0` pins using the RTS and DTR signals from the CH340C. This puts the ESP32 automatically into programming/bootloader mode when firmware is uploaded, and resets it to run mode once complete.
* **Type-C Negotiation**: Two 5.1kΩ pull-down resistors (`R7`, `R8`) on the CC1/CC2 pins advertise device capability, enabling standard Type-C power sources to negotiate and deliver 5V VBUS.
* **Decoupling & Protection**: 
  * A 100nF capacitor (`C5`) provides decoupling for the CH340C's supply.
  * 1kΩ series resistors (`R5`, `R6`) protect the RXD and TXD signal lines.
  * A 10kΩ pull-up resistor (`R11`) on the ESP32's `EN` pin ensures boot stability and noise rejection.

### Custom PCB Step-by-Step Instructions

#### 1. Assemble and Solder Components:
* Solder the SMT components in order of height (starting with resistors/capacitors, then the AP63300 IC, inductor, and finally the ESP32 module).
* Ensure correct alignment of pin 1 for the AP63300 (`U1`) and the ESP32-WROOM-32U (`U2`).

#### 2. Connect the Input:
* Connect the battery positive (+) terminal through an inline 1A fuse to pin 1 of the screw terminal block `J1` (labeled `12V`).
* Connect the battery negative (-) terminal to pin 2 of `J1` (labeled `GND`).
* Alternatively, plug a 12V DC power adapter (center-positive, 5.5x2.1mm barrel plug) into the female DC input jack `J4`.

#### 3. Connect the Display:
* Connect the SH1106 OLED I2C display to the 4-pin female socket/header `J2`. Pinout mappings are:
  * **Pin 1 (3.3V)** → OLED VCC
  * **Pin 2 (GND)** → OLED GND
  * **Pin 3 (SCL)** → OLED SCL
  * **Pin 4 (SDA)** → OLED SDA

---

## Detailed Pin Mappings & Configuration

### ESP32 Pin Assignment
| ESP32 Pin | Function | Schematic Net | Connection / Purpose |
|---|---|---|---|
| **GPIO34** | ADC Input (ADC1_CH6) | `V_ADC` | Voltage divider junction (Reads battery voltage) |
| **GPIO21** | I2C SDA | `SDA` | SH1106 OLED Display Data Line |
| **GPIO22** | I2C SCL | `SCL` | SH1106 OLED Display Clock Line |
| **3.3V** | Power Input | `3.3V` | Main power rail from buck converter |
| **GND** | Ground | `GND` | Common ground reference |

### Voltage Divider Formula & Scaling
The voltage divider uses $R_1 = 100\,\text{k}\Omega$ and $R_2 = 22\,\text{k}\Omega$.
$$V_{\text{ADC}} = V_{\text{Battery}} \times \left(\frac{R_2}{R_1 + R_2}\right) = V_{\text{Battery}} \times \left(\frac{22\,\text{k}\Omega}{122\,\text{k}\Omega}\right)$$
This yields a voltage scaling ratio of **$5.545$**.
* At $12.0\text{V}$ battery voltage, the ADC pin receives $2.16\text{V}$.
* At $14.6\text{V}$ (maximum charge for a 12V LiFePO4 battery), the ADC pin receives $2.63\text{V}$, which is safely under the ESP32's $3.3\text{V}$ limit.

---

## Testing & Calibration Procedure

### 1. Power Supply Test (Option A Only)
1. Connect the battery to the buck converter (with fuse).
2. Measure the buck converter output: should read `5.0V ± 0.1V`.
3. Adjust the converter output potentiometer if necessary.
4. Disconnect the battery.

### 2. Voltage Divider Test
1. Connect the voltage divider (or completed PCB) to the battery.
2. Measure the voltage at the junction point (where GPIO34 connects).
3. It should read `~3.0V` when connected to a 12V battery.
4. Disconnect the battery.

### 3. Complete System Test
1. Solder or connect all components.
2. Upload the firmware to the ESP32.
3. Connect the battery and observe the serial/display output.
4. Verify the voltage reading matches your multimeter reading (within `0.1V`).

---

## Wire Gauge & Color Coding Recommendations

### Wire Gauge
* **Power Lines (Battery to Board)**: Use **18-20 AWG** stranded wire. Red for positive, black for negative.
* **Signal Lines**: Use **22-24 AWG** stranded wire for low-current signals (<1 mA).

### Standard Colors
* **Red**: Battery positive (+), 5V/3.3V power lines
* **Black**: Ground (GND), battery negative (−)
* **Yellow/Orange**: Signal wires (e.g., I2C lines, ADC line)

---

## Safety Considerations

### Fuse Protection
* **Warning:** Always place a **1A inline fuse** on the positive line close to the battery. In case of a short circuit in the wiring or on the PCB, a 12V lead-acid or LiFePO4 battery can dump hundreds of amperes, creating a severe fire hazard.

### Grounding
* **Common Ground**: All ground connections (Battery negative, Buck converter ground, ESP32 ground, and Display ground) must be connected to a single reference net (`GND`).

### PCB Thermal Management
* Because the AP63300 is a highly efficient synchronous buck switching converter, it remains cool to the touch during normal operation. If the converter IC or inductor becomes hot, immediately disconnect power and check for a solder bridge or short circuit on the board.

---

## Troubleshooting

### ESP32 Won't Power On
* Check buck converter output voltage (5V for Option A, 3.3V for Option B).
* Verify ground connections.
* Check fuse continuity.
* Measure battery voltage (should be >10.5V).

### Wrong Voltage Readings
* Verify resistor values with a multimeter.
* Check for loose connections at the junction point or terminal blocks.
* Ensure GPIO34 pin is used (not another GPIO).
* Adjust the `VOLTAGE_DIVIDER_RATIO` constant in your software configurations.

### Intermittent Readings
* Check for loose wires, especially at junctions.
* Add a small capacitor (0.1µF) across $R_2$ for noise filtering and stability.
* Verify a solid common ground connection.

---

## Mounting & Enclosure Selection

### Mounting Options
* **Breadboard (Prototyping)**: Best for temporary testing, not suitable for permanent deployment.
* **Perfboard (Semi-Permanent)**: Solder components for reliability. Mount ESP32 with pin headers.
* **PCB (Permanent)**: Solder components directly to the custom PCB for a robust, professional design.

### Enclosure Selection
* **Indoor Use**: Basic plastic project box with ventilation holes.
* **Outdoor/Automotive Use**: Use an IP65+ rated weatherproof enclosure with cable glands to seal wire entry points.

---

## Power Consumption from Battery
With a standard deep-sleep configuration (e.g., 1-hour sleep interval):

| State | Current Draw (from 12V) | Time per Day |
|---|---|---|
| Active | ~50 mA | 30 seconds |
| Sleep | ~1-5 mA | 23h 59m 30s |
| **Average** | **~1-5 mA** | **24 hours** |

* **Daily consumption: ~1.3 mAh from 12V battery**

---

## Additional Resources

### Datasheets
* ESP32: https://www.espressif.com/en/products/socs/esp32
* AP63300 Buck Converter: https://www.diodes.com/assets/Datasheets/AP63300.pdf
* Sunlord Inductor (MPL2016S4R7MHT): http://www.sunlordinc.com

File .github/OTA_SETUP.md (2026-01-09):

# Automatic OTA Deployment Setup

This document explains how to configure GitHub Actions to automatically deploy firmware updates to your ESP32 devices via MQTT when you push a tag.

## Overview

The CI/CD workflow automatically:
1. **Nightly Builds**: Builds firmware every night at 2 AM UTC (stored as artifacts for 30 days)
2. **Tag Releases**: Creates GitHub releases when you push tags (only from `main` branch)
3. **OTA Deployment**: Publishes firmware URL to MQTT topic to trigger device updates

## GitHub Secrets Configuration

To enable automatic OTA deployment, configure these secrets in your repository:

**Settings → Secrets and variables → Actions → New repository secret**

### Required Secrets

| Secret Name | Description | Example |
|---|---|---|
| `OTA_MQTT_SERVER` | MQTT broker hostname | `cloudy.mbergeron.ca` |
| `OTA_MQTT_PORT` | MQTT broker port (usually 8883 for TLS) | `8883` |
| `OTA_MQTT_USER` | MQTT username for publishing | `ota_updater` |
| `OTA_MQTT_PASSWORD` | MQTT password | `your-secure-password` |
| `OTA_MQTT_TOPIC` | Topic to publish OTA URLs (optional) | `battery/monitor/ota` |

**Note:** If secrets are not configured, the workflow will skip the OTA deployment step and only create the GitHub release.

## Workflow Triggers

### 1. Tag Pushes (Releases)
```bash
# Create and push a tag from main branch
git checkout main
git tag v0.3.4
git push origin v0.3.4
```

**What happens:**
- ✅ Validates tag is on `main` branch
- ✅ Builds firmware with version `0.3.4`
- ✅ Creates GitHub release with firmware.bin
- ✅ Publishes OTA URL to MQTT topic
- ✅ Devices subscribed to MQTT topic auto-update

### 2. Nightly Builds (Scheduled)
Automatically runs at 2 AM UTC daily.

**What happens:**
- ✅ Builds firmware with version `nightly-YYYYMMDD-githash`
- ✅ Uploads firmware as GitHub artifact (30 day retention)
- ❌ Does NOT create release
- ❌ Does NOT trigger OTA deployment

### 3. Manual Trigger
Use the "Run workflow" button in GitHub Actions tab.

**What happens:**
- Same as nightly build
- Useful for testing or on-demand builds

## Tag Naming Convention

- **Format:** `v<major>.<minor>.<patch>`
- **Examples:** `v1.0.0`, `v0.3.4`, `v2.1.5`
- **Main branch only:** All tags must be created on the `main` branch

## How OTA Deployment Works

1. **Build Complete:** Firmware uploaded to GitHub release
2. **MQTT Publish:** Workflow publishes firmware URL to MQTT topic:
   ```
   Topic: battery/monitor/ota
   Payload: https://github.com/USER/REPO/releases/download/v0.3.4/firmware.bin
   QoS: 1 (at least once)
   Retain: true
   ```
3. **Device Detection:** ESP32 devices subscribed to topic receive URL
4. **Auto Update:** Devices download and install firmware on next wake cycle

## Testing the Setup

### Test MQTT Connection
```bash
# Install mosquitto clients
sudo apt-get install mosquitto-clients

# Test publish (replace with your credentials)
mosquitto_pub \
  -h cloudy.mbergeron.ca \
  -p 8883 \
  -u ota_updater \
  -P "your-password" \
  --capath /etc/ssl/certs \
  -t "battery/monitor/ota" \
  -m "https://github.com/USER/REPO/releases/download/v0.3.4/firmware.bin" \
  -q 1 \
  -r
```

### Monitor Device Response
```bash
# Subscribe to device status
mosquitto_sub \
  -h cloudy.mbergeron.ca \
  -p 8883 \
  -u esp32_user \
  -P "your-password" \
  --capath /etc/ssl/certs \
  -t "esp32-battery-monitor-0_availability/state" \
  -v
```

## Security Best Practices

1. **Separate MQTT User:** Use a dedicated `ota_updater` user with publish-only permissions
2. **ACL Configuration:** Restrict `ota_updater` to only publish to OTA topic
3. **Strong Passwords:** Use generated passwords (20+ characters)
4. **TLS/SSL:** Always use port 8883 with TLS encryption
5. **Secret Rotation:** Rotate MQTT credentials periodically

### Example Mosquitto ACL
```
# /etc/mosquitto/conf.d/acl.conf

# OTA updater - publish only
user ota_updater
topic write battery/monitor/ota

# ESP32 devices - read OTA updates
user esp32_user
topic read battery/monitor/ota
topic readwrite esp32-battery-monitor-+/#
```

## Troubleshooting

### Workflow Fails: "Tags can only be created on main branch"
**Solution:** 
```bash
git checkout main
git merge your-branch
git tag v0.3.4
git push origin main
git push origin v0.3.4
```

### OTA Deployment Skipped
**Check:** Are GitHub secrets configured?
```bash
# View workflow run to see if secrets are set
# Look for: "⚠️ OTA_MQTT_SERVER secret not set"
```

### Devices Not Updating
1. **Check MQTT topic:** Verify devices subscribe to correct topic
2. **Check retain flag:** Ensure message is retained for sleeping devices
3. **Check device logs:** Monitor serial output during wake cycle
4. **Test MQTT manually:** Use `mosquitto_pub` to test

### Build Fails
1. **Check credentials:** Ensure `wifi_credentials.h` and `mqtt_credentials.h` are created
2. **Clear cache:** Delete `.pio` folder and rebuild
3. **Check PlatformIO version:** Update to latest

## Workflow File Location

`.github/workflows/release.yml`

## Related Documentation

- [OTA.md](../doc/OTA.md) - Device-side OTA implementation
- [MQTT.md](../doc/MQTT.md) - MQTT integration details
- [AGENTS.md](../AGENTS.md) - Development best practices

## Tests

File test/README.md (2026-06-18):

# Battery Monitor Tests

This directory contains unit tests for the ESP32 Battery Monitor project using the PlatformIO Unity testing framework.

## Test Coverage

The test suite (`test_battery_monitor.cpp`) covers:

### Battery Percentage Calculation
- Full battery (100%)
- Above full voltage (capped at 100%)
- Minimum voltage (0%)
- Below minimum voltage (capped at 0%)
- Mid-range voltage (~50%)
- Nominal voltage
- Negative voltage handling
- Very high voltage handling

### Battery Status Determination
- FULL status
- GOOD status
- LOW status
- CRITICAL status
- DEAD status
- Boundary conditions between states
- Negative and zero voltage handling

### ADC to Voltage Conversion
- Zero ADC reading
- Maximum ADC reading (4095)
- Mid-range ADC reading
- Typical 12V battery reading
- Voltage divider ratio verification
- Safety verification (ADC input < 3.3V)

### Battery Type Configuration
- Correct threshold values for Lead-Acid
- Correct threshold values for LiFePO4
- Threshold ordering validation

## Running Tests

### Run Tests for Lead-Acid Battery
```bash
# Run tests on native platform (no hardware required)
pio test

# Run tests on ESP32 hardware
pio test -e esp32dev
```

### Run Tests for LiFePO4 Battery
```bash
# Run tests with LiFePO4 configuration
pio test -e esp32dev -D BATTERY_TYPE=BATTERY_TYPE_LIFEPO4
```

### Run Specific Test
```bash
# Run only battery percentage tests
pio test --filter test_battery_percentage_*

# Run only status tests
pio test --filter test_battery_status_*
```

## Test Output Example

```
======================================
Testing Battery Monitor - Lead-Acid
======================================

test/test_battery_monitor.cpp:77:test_battery_percentage_full [PASSED]
test/test_battery_monitor.cpp:82:test_battery_percentage_above_full [PASSED]
test/test_battery_monitor.cpp:87:test_battery_percentage_minimum [PASSED]
test/test_battery_monitor.cpp:92:test_battery_percentage_below_minimum [PASSED]
test/test_battery_monitor.cpp:97:test_battery_percentage_mid_range [PASSED]
test/test_battery_monitor.cpp:110:test_battery_percentage_nominal [PASSED]
...

-----------------------
32 Tests 0 Failures 0 Ignored 
OK
```

## Writing New Tests

To add new tests, follow this pattern:

```cpp
void test_your_test_name() {
  // Arrange - set up test data
  float testVoltage = 12.5;
  
  // Act - call function under test
  float result = calculateBatteryPercentage(testVoltage);
  
  // Assert - verify expected behavior
  TEST_ASSERT_FLOAT_WITHIN(1.0, 85.0, result);
}
```

Then add it to the `setup()` function:
```cpp
RUN_TEST(test_your_test_name);
```

## Test Assertions Available

- `TEST_ASSERT_EQUAL_FLOAT(expected, actual)`
- `TEST_ASSERT_FLOAT_WITHIN(delta, expected, actual)`
- `TEST_ASSERT_EQUAL_STRING(expected, actual)`
- `TEST_ASSERT_GREATER_THAN(threshold, actual)`
- `TEST_ASSERT_LESS_THAN(threshold, actual)`
- `TEST_ASSERT_TRUE(condition)`
- `TEST_ASSERT_FALSE(condition)`

## Known Issues

### Voltage Divider Safety and ESP32 ADC Specs

The voltage divider is configured using R1 = 100kΩ and R2 = 22kΩ resistors, resulting in a ratio of 5.545. This scales the maximum battery voltage down safely within the ESP32's ADC specifications (<= 3.3V) for both battery types:
- **Lead-Acid**: Max 12.7V maps to 2.29V at the ADC (safe, < 3.3V)
- **LiFePO4**: Max 14.6V maps to 2.63V at the ADC (safe, < 3.3V)

The safety test `test_voltage_divider_safety` verifies that the scaled voltage remains strictly below the 3.3V reference voltage.

## Continuous Integration

These tests can be integrated into CI/CD pipelines:

```yaml
# Example GitHub Actions
- name: Run PlatformIO Tests
  run: |
    pio test -e esp32dev
    pio test -e esp32dev -D BATTERY_TYPE=BATTERY_TYPE_LIFEPO4
```

## Troubleshooting

**Tests fail to compile:**
- Ensure PlatformIO is up to date: `pio upgrade`
- Check that Unity is installed: `pio lib install "Unity"`

**Tests timeout on hardware:**
- Increase test timeout in platformio.ini: `test_timeout = 120`
- Check serial connection and baud rate

**Float comparison failures:**
- Use `TEST_ASSERT_FLOAT_WITHIN()` instead of exact equality
- Adjust tolerance (delta) as needed for precision

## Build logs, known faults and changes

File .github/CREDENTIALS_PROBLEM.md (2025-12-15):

# Critical Issue: Credentials and OTA Updates

## The Problem

**You identified a critical flaw in the current implementation.**

When credentials are compiled into firmware using `#define`:
```cpp
#define WIFI_SSID "MyWiFi"
#define WIFI_PASSWORD "MyPassword"
```

These become **part of the binary**. When you do an OTA update:

```
┌─────────────────────────────────┐
│ Step 1: Initial Upload (USB)   │
│ Firmware with YOUR credentials  │
│ Device connects ✓               │
└─────────────────────────────────┘
         ↓
┌─────────────────────────────────┐
│ Step 2: OTA Update              │
│ New firmware with PLACEHOLDERS  │
│ YOUR credentials OVERWRITTEN    │
└─────────────────────────────────┘
         ↓
┌─────────────────────────────────┐
│ Result: Device can't connect ❌ │
│ WiFi: "your-wifi-ssid"          │
│ Password: "your-wifi-password"  │
└─────────────────────────────────┘
```

**The device will be bricked and require USB access to fix.**

## Solutions

### Solution 1: Use GitHub Secrets (Quick Fix)

**Best for:** Single installation or all devices using same credentials

#### Setup:
1. Add secrets to GitHub repository:
   - Go to: Settings → Secrets and variables → Actions
   - Add: `WIFI_SSID`, `WIFI_PASSWORD`, `MQTT_SERVER`, etc.

2. Edit `.github/workflows/release.yml`:
   - Comment out "Option A" (placeholder credentials)
   - Uncomment "Option B" (GitHub Secrets)

3. Push a new release tag:
   ```bash
   git tag v1.0.1
   git push origin v1.0.1
   ```

**Result:** All released binaries contain YOUR credentials. OTA updates work perfectly.

**Pros:**
- ✅ No code changes needed
- ✅ Works immediately
- ✅ OTA updates preserve credentials

**Cons:**
- ❌ All devices must use same credentials
- ❌ Not suitable for public repositories
- ❌ Not suitable for multiple installations with different WiFi networks

---

### Solution 2: Use NVS (Preferences) - Proper Solution

**Best for:** Multiple devices, different credentials per device, production use

Store credentials in ESP32's Non-Volatile Storage (NVS) instead of compiling them in. Credentials persist across OTA updates because they're in a separate memory partition.

#### Implementation:

Create a new file `include/config_manager.h`:
```cpp
#ifndef CONFIG_MANAGER_H
#define CONFIG_MANAGER_H

#include <Preferences.h>

class ConfigManager {
private:
    Preferences preferences;
    
public:
    // WiFi settings
    String wifiSSID;
    String wifiPassword;
    
    // MQTT settings
    String mqttServer;
    int mqttPort;
    String mqttUser;
    String mqttPassword;
    String mqttClientID;
    
    void begin() {
        preferences.begin("battery-mon", false);
        
        // Load WiFi credentials
        wifiSSID = preferences.getString("wifi_ssid", WIFI_SSID);
        wifiPassword = preferences.getString("wifi_pass", WIFI_PASSWORD);
        
        // Load MQTT credentials
        mqttServer = preferences.getString("mqtt_srv", MQTT_SERVER);
        mqttPort = preferences.getInt("mqtt_port", MQTT_PORT);
        mqttUser = preferences.getString("mqtt_user", MQTT_USER);
        mqttPassword = preferences.getString("mqtt_pass", MQTT_PASSWORD);
        mqttClientID = preferences.getString("mqtt_id", MQTT_CLIENT_ID);
        
        // On first run, save defaults to NVS
        if (!preferences.isKey("initialized")) {
            saveConfig();
            preferences.putBool("initialized", true);
        }
    }
    
    void saveConfig() {
        preferences.putString("wifi_ssid", wifiSSID);
        preferences.putString("wifi_pass", wifiPassword);
        preferences.putString("mqtt_srv", mqttServer);
        preferences.putInt("mqtt_port", mqttPort);
        preferences.putString("mqtt_user", mqttUser);
        preferences.putString("mqtt_pass", mqttPassword);
        preferences.putString("mqtt_id", mqttClientID);
    }
    
    void end() {
        preferences.end();
    }
};

#endif
```

Modify `main.cpp` to use ConfigManager:
```cpp
#include "config_manager.h"

ConfigManager config;

void setup() {
    Serial.begin(115200);
    
    // Load configuration from NVS
    config.begin();
    
    Serial.println("Configuration loaded:");
    Serial.println("WiFi SSID: " + config.wifiSSID);
    Serial.println("MQTT Server: " + config.mqttServer);
    
    // ... rest of setup
}

bool connectWiFi() {
    WiFi.begin(config.wifiSSID.c_str(), config.wifiPassword.c_str());
    // ... rest of function
}

bool connectMQTT() {
    mqttClient.setServer(config.mqttServer.c_str(), config.mqttPort);
    mqttClient.connect(config.mqttClientID.c_str(), 
                       config.mqttUser.c_str(), 
                       config.mqttPassword.c_str());
    // ... rest of function
}
```

**How it works:**
1. First upload: Reads compiled-in defaults, saves to NVS
2. Future boots: Reads from NVS (ignores compiled-in values)
3. OTA updates: New firmware reads from NVS, credentials preserved ✓

**Pros:**
- ✅ Credentials survive OTA updates
- ✅ Each device can have different credentials
- ✅ Can be updated via serial commands or web interface
- ✅ Industry standard approach

**Cons:**
- Requires code changes
- Slightly more complex

---

### Solution 3: WiFiManager (Most User-Friendly)

**Best for:** Non-technical users, field deployment

Use WiFiManager library for web-based configuration:

```cpp
#include <WiFiManager.h>

void setup() {
    WiFiManager wm;
    
    // Auto-connect or show config portal
    if (!wm.autoConnect("BatteryMonitor-Setup")) {
        Serial.println("Failed to connect");
        ESP.restart();
    }
    
    // Device is now connected with credentials saved in NVS
}
```

**How it works:**
1. First boot: Creates WiFi access point "BatteryMonitor-Setup"
2. User connects and enters WiFi/MQTT credentials via web interface
3. Credentials saved to NVS
4. Future boots and OTA updates use saved credentials

**Pros:**
- ✅ No credential files needed
- ✅ User-friendly web configuration
- ✅ Credentials survive OTA updates
- ✅ Can reset via button press

---

## Comparison

| Solution | OTA Safe | Multiple Devices | Public Repo | Ease of Use |
|---|---|---|---|---|
| GitHub Secrets | ✅ | Same creds only | ❌ | Easy |
| NVS (Preferences) | ✅ | ✅ | ✅ | Medium |
| WiFiManager | ✅ | ✅ | ✅ | Easy |

## Recommended Approach

### For Your Current Setup:
**Use Solution 1 (GitHub Secrets)** if:
- All your devices use the same WiFi network
- You have a private repository
- You want a quick fix

### For Production/Multiple Sites:
**Use Solution 2 (NVS)** because:
- Each device can have different credentials
- Proper separation of code and configuration
- Industry standard practice
- Credentials truly persist across OTA updates

## Example: How NVS Solves the Problem

```
┌─────────────────────────────────┐
│ First Upload (USB)              │
│ Firmware reads compiled defaults│
│ Saves to NVS partition         │
└─────────────────────────────────┘
         ↓
┌─────────────────────────────────┐
│ NVS Partition (separate)        │
│ WiFi: "MyNetwork"               │
│ Pass: "MyPassword"              │
│ [Persists across updates]       │
└─────────────────────────────────┘
         ↓
┌─────────────────────────────────┐
│ OTA Update                      │
│ New firmware installed          │
│ NVS partition UNTOUCHED         │
└─────────────────────────────────┘
         ↓
┌─────────────────────────────────┐
│ Device reboots                  │
│ New firmware reads NVS          │
│ Connects with YOUR credentials ✓│
└─────────────────────────────────┘
```

## Action Required

**You must choose one of these solutions before using OTA updates**, otherwise your devices will lose connectivity after the first OTA update.

Would you like me to implement Solution 2 (NVS) for you? It's the most robust approach.

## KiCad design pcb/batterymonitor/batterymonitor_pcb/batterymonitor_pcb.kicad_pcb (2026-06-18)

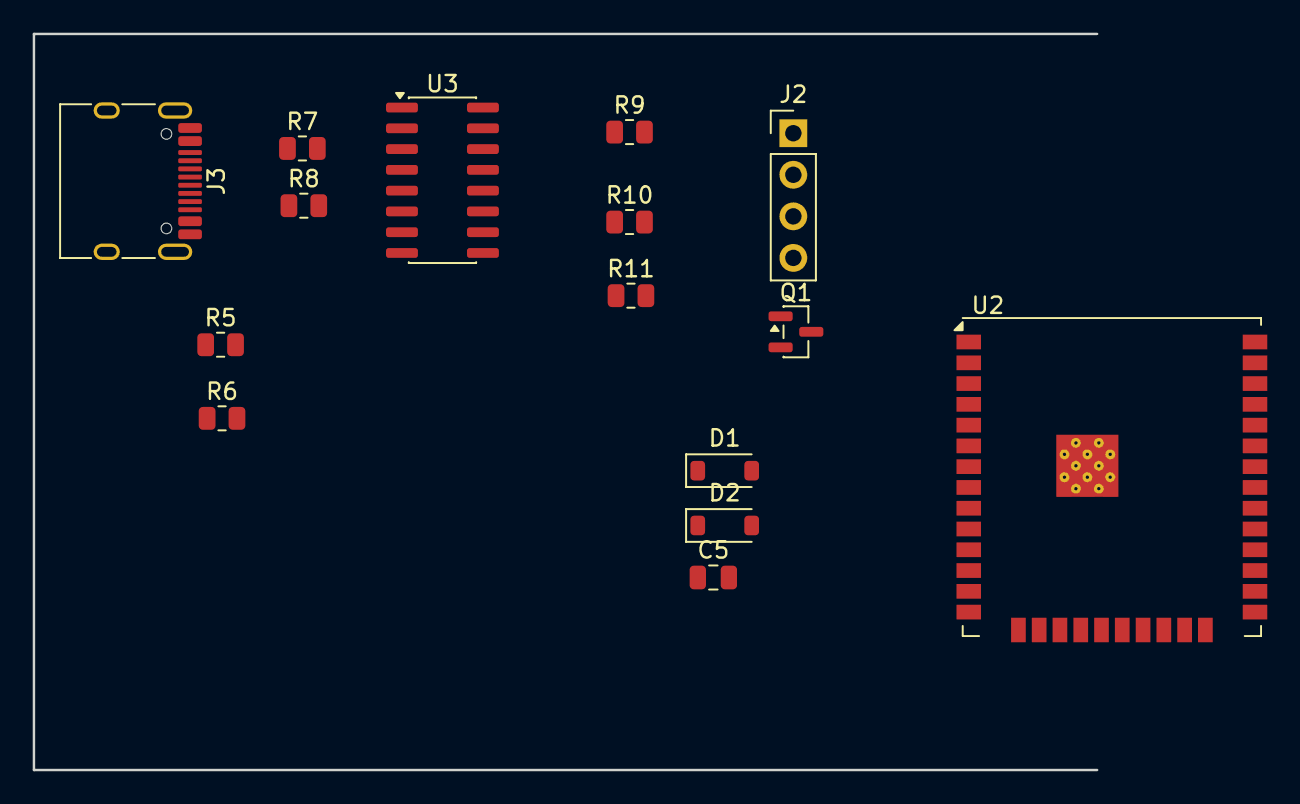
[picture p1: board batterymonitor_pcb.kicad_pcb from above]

Board: 2 copper layers, 65.0 x 45.0 mm, 15 parts (0 on the bottom side), 17 nets, no tracks yet.

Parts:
C5: 100nF/10V; C_0805_2012Metric
D1, D2: SS14; D_SOD-123
J2: Conn_01x04_Pin; PinHeader_1x04_P2.54mm_Vertical
J3: USB_C_Receptacle_HRO_TYPE-C-31-M-12
Q1: S8050; SOT-23
R5, R6: 1k; R_0805_2012Metric
R7, R8: 5.1k; R_0805_2012Metric
R9, R10, R11: 10k; R_0805_2012Metric
U2: ESP32-WROOM-32U-N4; ESP32-WROOM-32U
U3: CH340C; SOIC-16_3.9x9.9mm_P1.27mm

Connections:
/3.3V: C5.1, J2.1, R11.1, U2.2 (3V3), U3.5 (VCC), U3.6 (V3)
/12V: D1.1 (K), D2.1 (K)
/ESP_EN: Q1.3 (C), R11.2, U2.3 (EN)
/ESP_RXD: R5.2, U2.34 (RXD0)
/ESP_TXD: R6.1, U2.35 (TXD0), U3.8 (RXD)
/GND: C5.2, J2.2, J3.A1 (GND), J3.B12 (GND), J3.SH (SHIELD), R7.2, R8.2, U2.1 (GND), U2.15 (GND), U2.38 (GND), U3.3 (GND)
/SCL: J2.3, U2.36 (GPIO22)
/SDA: J2.4, U2.33 (GPIO21)
/USB_CC1: J3.A5 (CC1), R7.1
/USB_CC2: J3.B5 (CC2), R8.1
/USB_DN: J3.A7 (D-), J3.B7 (D-), U3.2 (UD-)
/USB_DP: J3.A6 (D+), J3.B6 (D+), U3.1 (UD+)
/USB_DTR: Q1.2 (E), R10.2, U3.9 (DTR)
/USB_RTS: R9.2, U3.14 (RTS)
/VBUS: D2.2 (A), J3.A4 (VBUS), J3.B9 (VBUS)
unnamed: Q1.1 (B), R9.1
unnamed: R5.1, U3.7 (TXD)

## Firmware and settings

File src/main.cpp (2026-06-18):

/*
 * ESP32 Battery Voltage Monitor with Deep Sleep & MQTT
 *
 * Monitors a 12V battery using a voltage divider circuit
 * Supports Lead-Acid and LiFePO4 battery types
 * Features deep sleep mode for ultra-low power consumption
 * Publishes readings to MQTT broker
 *
 * Hardware Setup:
 * - Battery + terminal -> R1 (100kΩ) -> ADC Pin (GPIO34) -> R2 (22kΩ) -> GND
 * - This creates a 5.55:1 voltage divider (12V becomes ~2.16V at ADC)
 *
 * Power Consumption:
 * - Active: ~80-160 mA (during reading, ~5 seconds)
 * - Deep Sleep: ~0.01 mA (between readings, 4 hours)
 * - Average: ~0.1-0.3 mA (>99.9% time in deep sleep)
 *
 * Battery Type: Set in platformio.ini with -D BATTERY_TYPE=LEAD_ACID or LIFEPO4
 * WiFi & MQTT: Configure in wifi_credentials.h and mqtt_credentials.h
 */

#include <Arduino.h>
#include <WiFi.h>
#include <WiFiClientSecure.h>
#include <PubSubClient.h>
#include <driver/rtc_io.h>
#include <driver/gpio.h>
#include "battery_monitor.h"
#include "esp_sleep.h"
#include "config_manager.h"
#include "network_manager.h"
#include "ota_manager.h"
#include "command_handler.h"
#include "display_manager.h"

// Include credentials (create these files!)
// These are now used as DEFAULT VALUES only - actual credentials stored in NVS
#include "wifi_credentials.h" // Defines WIFI_SSID and WIFI_PASSWORD
#include "mqtt_credentials.h" // Defines MQTT_SERVER, MQTT_PORT, MQTT_USER, MQTT_PASSWORD, MQTT_CLIENT_ID

// RTC memory to preserve data across deep sleep
RTC_DATA_ATTR int bootCount = 0;
RTC_DATA_ATTR float lastVoltage = 0.0;
RTC_DATA_ATTR bool applianceForcedOff = false;
RTC_DATA_ATTR int wifiFailCount = 0;

// Global objects
BatteryMonitor monitor;
WiFiClientSecure wifiClient;
PubSubClient mqttClient(wifiClient);
ConfigManager config; // Manages credentials in NVS (persists across OTA updates)
NetworkManager network(wifiClient, mqttClient, config);
CommandHandler commandHandler(config);
DisplayManager display;
OTAManager otaManager(config, &display);

void printWakeupReason()
{
  esp_sleep_wakeup_cause_t wakeup_reason = esp_sleep_get_wakeup_cause();

  switch (wakeup_reason)
  {
  case ESP_SLEEP_WAKEUP_TIMER:
    Serial.println("Wakeup caused by timer");
    break;
  case ESP_SLEEP_WAKEUP_EXT0:
    Serial.println("Wakeup caused by external signal using RTC_IO");
    break;
  case ESP_SLEEP_WAKEUP_EXT1:
    Serial.println("Wakeup caused by external signal using RTC_CNTL");
    break;
  case ESP_SLEEP_WAKEUP_TOUCHPAD:
    Serial.println("Wakeup caused by touchpad");
    break;
  case ESP_SLEEP_WAKEUP_ULP:
    Serial.println("Wakeup caused by ULP program");
    break;
  default:
    Serial.println("Wakeup was not caused by deep sleep (first boot)");
    break;
  }
}

void enterDeepSleep()
{
  // Ensure timezone is set (in case WiFi didn't connect)
  setenv("TZ", "EST5EDT,M3.2.0,M11.1.0", 1);
  tzset();
  
  // Calculate next wakeup time
  time_t now;
  time(&now);
  time_t wakeupTime = now + (Config::DEEP_SLEEP_INTERVAL_US / 1000000);
  struct tm* timeinfo = localtime(&wakeupTime);
  
  char wakeupISO[25];
  strftime(wakeupISO, sizeof(wakeupISO), "%Y-%m-%dT%H:%M:%S", timeinfo);
  
  Serial.println("\n─────────────────────────────────");
  Serial.println("Entering deep sleep mode...");
  Serial.print("Next reading in: ");
  Serial.print(Config::DEEP_SLEEP_INTERVAL_US / 1000000);
  Serial.println(" seconds");
  Serial.print("Wake at: ");
  Serial.println(wakeupISO);
  Serial.println("Power consumption: ~10 µA");
  Serial.println("─────────────────────────────────");
  
  // Show sleep screen on display
  if (display.isReady()) {
    display.showSleepScreen(wakeupTime, monitor.readBattery());
    delay(2000); // Show sleep screen for 2 seconds
  }
  
  Serial.flush(); // Wait for serial transmission to complete

  // Configure timer wakeup
  esp_sleep_enable_timer_wakeup(Config::DEEP_SLEEP_INTERVAL_US);

  // Enable GPIO hold for the relay pin to maintain state during sleep
  if (rtc_gpio_is_valid_gpio((gpio_num_t)Config::APPLIANCE_RELAY_PIN)) {
      rtc_gpio_hold_en((gpio_num_t)Config::APPLIANCE_RELAY_PIN);
  } else {
      gpio_hold_en((gpio_num_t)Config::APPLIANCE_RELAY_PIN);
  }

  // Enter deep sleep
  esp_deep_sleep_start();
}

void setup()
{
  // Disable GPIO hold on boot to allow reconfiguration
  if (rtc_gpio_is_valid_gpio((gpio_num_t)Config::APPLIANCE_RELAY_PIN)) {
      rtc_gpio_hold_dis((gpio_num_t)Config::APPLIANCE_RELAY_PIN);
  } else {
      gpio_hold_dis((gpio_num_t)Config::APPLIANCE_RELAY_PIN);
  }
  
  // Initialize appliance relay pin
  pinMode(Config::APPLIANCE_RELAY_PIN, OUTPUT);

  // Initialize serial communication
  Serial.begin(Config::SERIAL_BAUD_RATE);
  delay(500); // Short delay for serial connection

  // Increment boot count
  bootCount++;

  // Print boot information
  Serial.println("\n╔═════════════════════════════════════╗");
  Serial.println("║  ESP32 Battery Monitor (Deep Sleep) ║");
  Serial.println("╚═════════════════════════════════════╝");
  Serial.print("Boot count: ");
  Serial.println(bootCount);

  // Print wakeup reason
  printWakeupReason();

  if (bootCount > 1)
  {
    Serial.print("Last voltage: ");
    Serial.print(lastVoltage, 2);
    Serial.println(" V");
  }

  Serial.println();

  // Initialize display early
  display.begin();
  if (display.isReady()) {
    display.showBootScreen(bootCount);
    delay(1000); // Show boot screen for 1 second
  }

  // Initialize configuration manager (loads from NVS or uses defaults on first run)
  config.begin(WIFI_SSID, WIFI_PASSWORD,
               MQTT_SERVER, MQTT_PORT,
               MQTT_USER, MQTT_PASSWORD,
               MQTT_CLIENT_ID);

  // Apply battery chemistry from NVS
  if (config.batteryType.equalsIgnoreCase("lifepo4")) {
    BatteryMonitor::setChemistry(BatteryChemistry::LIFEPO4);
    Serial.println("Battery chemistry set from NVS: LiFePO4");
  } else {
    BatteryMonitor::setChemistry(BatteryChemistry::LEAD_ACID);
    Serial.println("Battery chemistry set from NVS: Lead-Acid");
  }

  // Check for pending OTA update from previous wake cycle
  if (otaManager.checkPendingOTA())
  {
    Serial.println("OTA update was triggered while device was asleep.");
    Serial.println("Processing OTA update now...");
    
    if (display.isReady()) {
      display.showOTAScreen("Processing...");
    }
    
    // Connect to WiFi for OTA
    if (network.connectWiFi())
    {
      wifiFailCount = 0;
      otaManager.setup();
      otaManager.handleUpdate();
      // If we reach here, OTA timed out or failed
      // Continue with normal operation
      network.disconnect();
    }
    else
    {
      Serial.println("Failed to connect to WiFi for OTA. Will retry next boot.");
    }
  }
  // Automatically check for available updates on every wake
  else if (Config::AUTO_CHECK_OTA)
  {
    if (display.isReady()) {
      display.showOTAScreen("Checking...");
    }
    
    // Connect to WiFi to check for updates
    if (network.connectWiFi())
    {
      wifiFailCount = 0;
      // Check if a newer version is available
      if (otaManager.checkForUpdates())
      {
        // New version found and OTA requested
        otaManager.setup();
        otaManager.handleUpdate();
        // If we reach here, OTA timed out or failed
        // Continue with normal operation
      }
      network.disconnect();
    }
    else
    {
      Serial.println("Failed to connect to WiFi for update check.");
    }
  }

  // Initialize battery monitor
  monitor.begin();

  // Print battery type info (only on first boot)
  if (bootCount == 1)
  {
    monitor.printStartupInfo();
  }

  // Set up OTA and network callbacks
  network.setOTACallback([](const String &filename)
                         { otaManager.requestUpdate(filename); });

  network.setResetCallback([]()
                           {
    config.clear();
    Serial.println("NVS will be cleared. Rebooting in 2 seconds...");
    delay(2000);
    ESP.restart(); });
}

void loop()
{
  // Take reading immediately
  BatteryReading reading = monitor.readBattery();

  // Evaluate appliance relay logic with hysteresis:
  // - Turns OFF if voltage < cutoff
  // - Reactivates only if voltage >= recovery (if target state is ON)
  bool isLow = reading.voltage < BatteryMonitor::getApplianceCutoff();
  bool isRecovered = reading.voltage >= BatteryMonitor::getApplianceRecovery();
  bool actualState = false;

  if (config.applianceTargetState) {
    if (applianceForcedOff) {
      if (isRecovered) {
        applianceForcedOff = false;
        actualState = true;
        Serial.println("✅ Appliance voltage recovered. Reactivating relay.");
      } else {
        actualState = false;
        Serial.printf("⏳ Appliance waiting for recovery threshold (%.2fV). Current: %.2fV\n", 
                      BatteryMonitor::getApplianceRecovery(), reading.voltage);
      }
    } else {
      if (isLow) {
        applianceForcedOff = true;
        actualState = false;
        Serial.println("⚠️  Battery voltage critical for appliance. Forcing relay OFF.");
      } else {
        actualState = true;
      }
    }
  } else {
    // If target state is OFF, reset the forced flag and keep relay off
    applianceForcedOff = false;
    actualState = false;
  }

  digitalWrite(Config::APPLIANCE_RELAY_PIN, actualState ? HIGH : LOW);
  
  if (config.applianceTargetState) {
    if (actualState) {
      Serial.println("Appliance relay is: ON (Battery OK)");
    }
  } else {
    Serial.println("Appliance relay is: OFF (Target is OFF)");
  }

  // Store voltage in RTC memory
  lastVoltage = reading.voltage;

  // Display reading
  monitor.printReading(reading);

  // Update display with battery info (WiFi not connected yet)
  if (display.isReady()) {
    display.update(reading, false, 0);
  }

  // Connect to WiFi and MQTT, then publish
  Serial.println("\n─────────────────────────────────");
  if (network.connectWiFi())
  {
    // Reset consecutive failures on success
    wifiFailCount = 0;
    
    // Get WiFi RSSI
    int8_t rssi = WiFi.RSSI();
    
    // Update display with WiFi info
    if (display.isReady()) {
      display.update(reading, true, rssi);
    }
    // Initialize OTA early (only once per wake cycle)
    static bool otaInitialized = false;
    if (!otaInitialized)
    {
      otaManager.setup();
      otaInitialized = true;
    }

    if (network.connectMQTT())
    {
      // Calculate next reading time for MQTT publishing
      time_t now;
      time(&now);
      time_t nextReading = now + (Config::DEEP_SLEEP_INTERVAL_US / 1000000);
      
      network.publishReading(reading, bootCount, nextReading);

      // Process MQTT messages for a few seconds to check for OTA trigger
      Serial.println("Checking for MQTT commands...");
      unsigned long checkStart = millis();
      while (millis() - checkStart < 3000)
      {
        network.loop();
        
        // Update display periodically
        if (display.isReady() && millis() % 500 < 100) {
          display.update(reading, true, WiFi.RSSI());
        }
        
        delay(100);

        // If OTA is requested, handle it
        if (otaManager.isUpdateRequested())
        {
          if (display.isReady()) {
            display.showOTAScreen("Starting...");
          }
          otaManager.handleUpdate();
          break;
        }
      }
    }
    
    // Disconnect to save power (unless in OTA mode)
    if (!otaManager.isUpdateRequested())
    {
      network.disconnect();
    }
  }
  else
  {
    wifiFailCount++;
    Serial.printf("WiFi connection failed. Consecutive failures: %d/%d\n", wifiFailCount, Config::WIFI_MAX_FAILURES);
    
    if (wifiFailCount >= Config::WIFI_MAX_FAILURES)
    {
      // Reset fail count before entering AP mode (so we start fresh next time)
      wifiFailCount = 0;
      
      // Start configuration portal
      network.startAPMode(reading, display, commandHandler);
    }
  }
  Serial.println("─────────────────────────────────");

  // Check for serial commands (for configuration/debugging)
  commandHandler.checkCommands();

  // Additional info
  Serial.print("Time awake: ");
  Serial.print(millis());
  Serial.println(" ms");

  // Don't enter deep sleep if OTA update is requested/in progress
  if (otaManager.isUpdateRequested())
  {
    Serial.println("OTA update requested - staying awake");
    Serial.println("Device will remain active to handle OTA update");
    delay(Config::READING_INTERVAL_MS);
  }
  else if (config.deepSleepEnabled && Config::ENABLE_DEEP_SLEEP)
  {
    // On first boot, wait longer to allow serial commands
    if (bootCount == 1)
    {
      Serial.println("First boot: waiting 30 seconds before deep sleep...");
      Serial.println("Type 'nosleep' to keep device awake.");
      unsigned long waitStart = millis();
      while (millis() - waitStart < 30000)
      {
        commandHandler.checkCommands();
        delay(200);
      }
      
      // Re-check if deep sleep is still enabled after the wait period
      // (user may have disabled it with 'nosleep' command)
      if (!config.deepSleepEnabled)
      {
        Serial.println("Deep sleep was disabled during wait period");
        // Don't enter deep sleep - fall through to stay awake
      }
      else
      {
        // Wait a moment for any processing
        delay(2000);
        // Enter deep sleep
        enterDeepSleep();
      }
    }
    else
    {
      // Not first boot - enter deep sleep immediately
      delay(2000);
      enterDeepSleep();
    }
  }
  
  // If we reach here, deep sleep is disabled or was disabled during first boot wait
  if (!config.deepSleepEnabled)
  {
    // Stay awake and listen for commands
    Serial.println("Deep sleep disabled, staying awake...");
    Serial.println("Type 'sleep' to re-enable deep sleep");
    
    // Keep listening for commands with periodic updates
    unsigned long loopStart = millis();
    while (millis() - loopStart < Config::READING_INTERVAL_MS)
    {
      commandHandler.checkCommands();
      delay(200);
    }
  }
}

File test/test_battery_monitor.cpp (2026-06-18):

/*
 * Unit Tests for ESP32 Battery Monitor
 * 
 * Tests the battery monitoring logic including:
 * - Voltage to percentage conversion
 * - Battery status determination
 * - Voltage calculations
 * - Boundary conditions
 * 
 * Note: These tests run on ESP32 hardware. Code compiles successfully.
 * To run tests, connect ESP32 and execute: pio test -e esp32dev
 */

#include <Arduino.h>
#include <unity.h>
#include "battery_monitor.h"

// Test helper to verify library is loaded correctly
void test_library_loaded() {
  // Just verify we can access the constants
  TEST_ASSERT_TRUE(VOLTAGE_FULL > 0);
  TEST_ASSERT_TRUE(VOLTAGE_MIN > 0);
  TEST_ASSERT_NOT_NULL(BATTERY_TYPE_NAME);
}

// ============================================================================
// TEST: Battery Percentage Calculation
// ============================================================================

void test_battery_percentage_full() {
  float percentage = calculateBatteryPercentage(VOLTAGE_FULL);
  TEST_ASSERT_EQUAL_FLOAT(100.0, percentage);
}

void test_battery_percentage_above_full() {
  float percentage = calculateBatteryPercentage(VOLTAGE_FULL + 0.5);
  TEST_ASSERT_EQUAL_FLOAT(100.0, percentage);
}

void test_battery_percentage_minimum() {
  float percentage = calculateBatteryPercentage(VOLTAGE_MIN);
  TEST_ASSERT_EQUAL_FLOAT(0.0, percentage);
}

void test_battery_percentage_below_minimum() {
  float percentage = calculateBatteryPercentage(VOLTAGE_MIN - 0.5);
  TEST_ASSERT_EQUAL_FLOAT(0.0, percentage);
}

void test_battery_percentage_mid_range() {
  #if BATTERY_TYPE == BATTERY_TYPE_LEAD_ACID
    // For Lead-Acid: 11.6V should be ~50%
    // Range: 10.5V to 12.7V = 2.2V span
    // 11.6V is 1.1V above minimum = 50%
    float percentage = calculateBatteryPercentage(11.6);
    TEST_ASSERT_FLOAT_WITHIN(1.0, 50.0, percentage);
  #elif BATTERY_TYPE == BATTERY_TYPE_LIFEPO4
    // For LiFePO4: 12.3V should be ~50%
    // Range: 10.0V to 14.6V = 4.6V span
    // 12.3V is 2.3V above minimum = 50%
    float percentage = calculateBatteryPercentage(12.3);
    TEST_ASSERT_FLOAT_WITHIN(1.0, 50.0, percentage);
  #endif
}

void test_battery_percentage_nominal() {
  float percentage = calculateBatteryPercentage(VOLTAGE_NOMINAL);
  TEST_ASSERT_GREATER_THAN(50.0, percentage);
  TEST_ASSERT_LESS_THAN(100.0, percentage);
}

// ============================================================================
// TEST: Battery Status Determination
// ============================================================================

void test_battery_status_full() {
  String status = getBatteryStatus(VOLTAGE_FULL);
  TEST_ASSERT_EQUAL_STRING("FULL", status.c_str());
}

void test_battery_status_above_full() {
  String status = getBatteryStatus(VOLTAGE_FULL + 0.5);
  TEST_ASSERT_EQUAL_STRING("FULL", status.c_str());
}

void test_battery_status_good() {
  String status = getBatteryStatus(VOLTAGE_NOMINAL);
  TEST_ASSERT_EQUAL_STRING("GOOD", status.c_str());
}

void test_battery_status_low() {
  String status = getBatteryStatus(VOLTAGE_LOW);
  TEST_ASSERT_EQUAL_STRING("LOW", status.c_str());
}

void test_battery_status_critical() {
  String status = getBatteryStatus(VOLTAGE_CRITICAL);
  TEST_ASSERT_EQUAL_STRING("CRITICAL", status.c_str());
}

void test_battery_status_dead() {
  String status = getBatteryStatus(VOLTAGE_MIN);
  TEST_ASSERT_EQUAL_STRING("DEAD", status.c_str());
}

void test_battery_status_boundary_full_good() {
  String status = getBatteryStatus(VOLTAGE_FULL - 0.01);
  TEST_ASSERT_EQUAL_STRING("GOOD", status.c_str());
}

void test_battery_status_boundary_good_low() {
  String status = getBatteryStatus(VOLTAGE_LOW + 0.01);
  TEST_ASSERT_EQUAL_STRING("LOW", status.c_str());
}

// ============================================================================
// TEST: ADC to Voltage Conversion
// ============================================================================

void test_adc_conversion_zero() {
  float voltage = adcToBatteryVoltage(0);
  TEST_ASSERT_EQUAL_FLOAT(0.0, voltage);
}

void test_adc_conversion_max() {
  // Max ADC (4095) should give 3.3V at ADC, which is 18.3V at battery (3.3 * 5.545)
  float voltage = adcToBatteryVoltage(4095);
  TEST_ASSERT_FLOAT_WITHIN(0.01, 18.2985, voltage);
}

void test_adc_conversion_mid() {
  // Half ADC (2048) should give ~1.65V at ADC, which is ~9.15V at battery (1.65 * 5.545)
  float voltage = adcToBatteryVoltage(2048);
  TEST_ASSERT_FLOAT_WITHIN(0.1, 9.15, voltage);
}

void test_adc_conversion_typical_12v() {
  // 12V battery = 2.164V at ADC = ADC reading of ~2685
  // Reverse: ADC 2685 should give ~12V
  float voltage = adcToBatteryVoltage(2685);
  TEST_ASSERT_FLOAT_WITHIN(0.1, 12.0, voltage);
}

// ============================================================================
// TEST: Voltage Divider Calculations
// ============================================================================

void test_voltage_divider_ratio() {
  // With 100kΩ and 22kΩ resistors: ratio = (100k + 22k) / 22k = 5.545
  TEST_ASSERT_EQUAL_FLOAT(5.545, VOLTAGE_DIVIDER_RATIO);
}

void test_voltage_divider_safety() {
  // Max battery voltage through divider should not exceed ADC reference
  // For Lead-Acid: 12.7V / 5.545 = 2.29V (safe, < 3.3V)
  // For LiFePO4: 14.6V / 5.545 = 2.633V (safe, < 3.3V)
  float maxAdcVoltage = VOLTAGE_FULL / VOLTAGE_DIVIDER_RATIO;
  
  TEST_ASSERT_LESS_THAN(ADC_REFERENCE_VOLTAGE, maxAdcVoltage);
}

// ============================================================================
// TEST: Battery Type Configuration
// ============================================================================

void test_battery_type_thresholds() {
  #if BATTERY_TYPE == BATTERY_TYPE_LEAD_ACID
    TEST_ASSERT_EQUAL_STRING("Lead-Acid", BATTERY_TYPE_NAME);
    TEST_ASSERT_EQUAL_FLOAT(12.7, VOLTAGE_FULL);
    TEST_ASSERT_EQUAL_FLOAT(10.5, VOLTAGE_MIN);
  #elif BATTERY_TYPE == BATTERY_TYPE_LIFEPO4
    TEST_ASSERT_EQUAL_STRING("LiFePO4", BATTERY_TYPE_NAME);
    TEST_ASSERT_EQUAL_FLOAT(14.6, VOLTAGE_FULL);
    TEST_ASSERT_EQUAL_FLOAT(10.0, VOLTAGE_MIN);
  #endif
}

void test_battery_threshold_order() {
  // Verify thresholds are in correct order
  TEST_ASSERT_GREATER_THAN(VOLTAGE_MIN, VOLTAGE_CRITICAL);
  TEST_ASSERT_GREATER_THAN(VOLTAGE_CRITICAL, VOLTAGE_LOW);
  TEST_ASSERT_GREATER_THAN(VOLTAGE_LOW, VOLTAGE_NOMINAL);
  TEST_ASSERT_GREATER_THAN(VOLTAGE_NOMINAL, VOLTAGE_FULL);
}

// ============================================================================
// TEST: Edge Cases and Robustness
// ============================================================================

void test_battery_percentage_negative_voltage() {
  float percentage = calculateBatteryPercentage(-1.0);
  TEST_ASSERT_EQUAL_FLOAT(0.0, percentage);
}

void test_battery_percentage_very_high_voltage() {
  float percentage = calculateBatteryPercentage(20.0);
  TEST_ASSERT_EQUAL_FLOAT(100.0, percentage);
}
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

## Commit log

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2025-12-10 Add comprehensive unit tests and refactor code into library
    - Created BatteryMonitor library with battery_monitor.h/cpp
    - Refactored shared functions (calculateBatteryPercentage, getBatteryStatus, adcToBatteryVoltage)
    - Added 32 unit tests covering:
    - Battery percentage calculations
    - Battery status determination
    - ADC to voltage conversion
    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
2025-12-10 Refactor: Object-oriented design with improved architecture
    Major improvements:
    - Introduced BatteryMonitor class for better encapsulation
    - Created battery_config.h for centralized configuration
    - Added BatteryStatus enum and BatteryReading struct
    - Separated concerns: config, library, and application
    - Improved code organization with namespaces
    New features:
    - BatteryReading structure with timestamp
    - Static helper methods for calculations
    - Better const correctness with constexpr
    - Enhanced display with emoji indicators
    Documentation:
    - Added advanced_monitoring.cpp example
    - Created comprehensive examples/README.md
    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
    [advanced_monitoring.cpp, main.cpp]
2025-12-11 Add deep sleep mode for ultra-low power consumption
    Power optimization:
    - Reduced average current from 80-160 mA to 0.12-0.23 mA (99.8% reduction)
    - Changed reading interval from 2 seconds to 1 hour
    - Added ESP32 deep sleep between readings (~10 µA)
    - Battery life extended from days to years (700x improvement)
    Features:
    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
2025-12-11 Update README with deep sleep power features
    Highlight ultra-low power consumption in main README:
    - Power consumption comparison table
    - Link to detailed DEEP_SLEEP.md documentation
    - Emphasize power efficiency as key feature
2025-12-11 Change deep sleep interval from 1 hour to 4 hours
    - Reduced wake-ups from 24 to 6 per day
    - Deep sleep interval: 3600s → 14400s (4 hours)
    - Further reduces daily power consumption
    - Daily consumption: 4.24 mAh → ~1.3 mAh
    - Even longer battery life with fewer interruptions
    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
2025-12-11 Add comprehensive wiring guide and hardware documentation
    Complete hardware setup documentation:
    - Detailed wiring diagrams with ASCII art
    - Component list with specifications
    - Step-by-step connection instructions
    - Pin configuration reference
    - Wire gauge recommendations
    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
2025-12-11 Add 3D printable enclosure design files
    Created parametric OpenSCAD design for battery monitor enclosure:
    Design features:
    - 100×70×40mm enclosure with rounded corners
    - ESP32 mounting posts with M3 screw holes
    - Cable entry holes for power and voltage divider
    - Ventilation slots in lid for heat dissipation
    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
    [battery_monitor_enclosure.scad]
2025-12-11 Separate enclosure into individual bottom and lid files
    Split the combined enclosure design into two separate files for easier workflow:
    New files:
    - battery_monitor_bottom.scad - Bottom part with mounting posts
    - battery_monitor_lid.scad - Lid part with ventilation
    Benefits:
    - No need to comment/uncomment code sections
    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
    [battery_monitor_bottom.scad, battery_monitor_lid.scad]
2025-12-13 Add MQTT publishing for remote battery monitoring
    Implemented MQTT functionality to publish battery readings to an MQTT broker:
    - WiFi connection with configurable timeout
    - MQTT client using PubSubClient library
    - Publishes voltage, percentage, status, type, boot count
    - JSON topic with all data + WiFi RSSI
    - Retained messages for last-value caching
    - Auto-disconnect after publish to save power
    Configuration:
    - WiFi credentials in include/wifi_credentials.h
    - MQTT broker settings in include/mqtt_credentials.h
    - Template files provided (.example)
    - Credentials excluded from git via .gitignore
    MQTT Topics:
    - battery/monitor/voltage - Battery voltage
    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
    [main.cpp]
2025-12-13 Update config and MQTT publishing logic
    - Tweak WiFi/MQTT timeouts and configuration in battery_config.h
    - Adjust MQTT publish flow in main.cpp for reliability and power
    - Prep for remote monitoring with retained JSON payloads
2025-12-13 remove enclosure and separate in two scad files
    [battery_monitor_enclosure.scad]
2025-12-15 refactor: extract manager classes for better separation of concerns
    - Create NetworkManager class (224 lines)
    - WiFi and MQTT connection management
    - Callback system for OTA and reset triggers
    - Publishing and disconnect handling
    - Create OTAManager class (214 lines)
    - ArduinoOTA and HTTP update handling
    - Unified OTA request/handling interface
    - Create CommandHandler class (205 lines)
    - Serial command parsing and execution
    - Configuration and system commands
    - Simplify main.cpp from 725 to 215 lines (70% reduction)
    - Clean separation of concerns
    - Improved readability and maintainability
    - Easier testing and reusability
    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
    [main.cpp]
2025-12-15 fix: prevent deep sleep during OTA updates
    - Add check to keep device awake when OTA update is requested
    - Ensures OTA updates can complete without sleep interruption
    - Device stays active with clear status messages during OTA
    [main.cpp]
2025-12-16 feat: Add DHCP support, persistent OTA triggers, and automatic update checking
    - Switch from static IP to DHCP by default (configurable via USE_STATIC_IP flag)
    - Implement persistent OTA trigger storage across deep sleep cycles using ESP32 Preferences
    - Add automatic version checking on every wake cycle
    - Firmware now checks GitHub for newer versions and auto-updates when available
    - OTA updates triggered via MQTT are now persisted and processed on next boot
    - Add version tracking (FIRMWARE_VERSION) and configurable OTA_VERSION_URL
    - Both manual MQTT-triggered and automatic version-based OTA updates supported
    - OTA triggers properly cleared after successful update, timeout, or failure
    [main.cpp]
2025-12-16 feat: Add version number to firmware binaries in release workflow
    - Extract version from git tag and inject as FIRMWARE_VERSION build flag
    - Generate firmware files with versioned names (firmware-leadacid-v1.0.0.bin)
    - Support automatic OTA update file naming convention
    - Include both versioned and legacy filenames for backward compatibility
    - Update release notes to document automatic update feature
    - Device can now automatically discover and install updates using version.txt
2025-12-16 refactor: Replace version.txt URL check with config-based OTA target version
    - Remove automatic version.txt fetching from URL
    - Add otaTargetVersion to ConfigManager (persisted in NVS)
    - Update checkForUpdates() to use configured target version instead of fetching
    - Add 'otaver' serial command to set OTA target version
    - Version checking now controlled via local config instead of remote file
    - Simpler and more predictable OTA behavior
    - Allows manual control over when devices should update
2025-12-16 fix: Include battery type in automatic OTA firmware filename
    - OTA manager now constructs filename as firmware-leadacid-v1.0.2.bin
    - Matches the naming convention from GitHub release workflow
    - Automatically detects BATTERY_TYPE (LEAD_ACID or LIFEPO4) at compile time
    - Ensures correct firmware variant is downloaded for each device type
2025-12-16 fix: Remove /latest/ from OTA_BASE_URL in platformio.ini
    - Changed from /releases/latest/download/ to /releases/download/
    - Device now constructs full path with version: v1.0.2/firmware-leadacid.bin
    - Applied to all three ESP32 environments
2025-12-16 fix: Clear OTA trigger before update attempt, not after
    - Clear persistent trigger at START of update process
    - Prevents re-triggering after successful update and reboot
    - HTTPUpdate library auto-reboots on success, code after may not run
    - Clears for both HTTP and ArduinoOTA modes
    - Eliminates update loops caused by persistent trigger
2025-12-16 feat: Add hostname and firmware version to MQTT payload
    - Publish hostname to battery/monitor/hostname topic
    - Publish firmware version to battery/monitor/version topic
    - Include both in JSON payload
    - Helps identify device and track deployed firmware versions
2025-12-16 feat: Add Home Assistant MQTT Discovery support
    - Publish discovery configs on MQTT connect
    - Auto-creates sensors in Home Assistant
    - Sensors: voltage, battery level, status, WiFi signal, boot count
    - Includes device information with firmware version
    - Uses standard HA device classes and state classes
2025-12-16 refactor: Use only Home Assistant MQTT topics
    - Remove legacy battery/monitor/* topics
    - Publish only to homeassistant/sensor/<hostname>/*/state topics
    - Cleaner topic structure following HA conventions
    - All sensors under homeassistant/ namespace
2025-12-16 feat: Add last updated timestamp sensor
    - Publish seconds since boot as last_updated sensor
    - Shows when voltage was last checked
    - Adds clock-check icon in Home Assistant
    - Helps monitor device health and reading frequency
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2025-12-16 refactor: Use device-based MQTT discovery with single state topic
    - Publish one JSON payload to homeassistant/sensor/<hostname>/state
    - All sensors use value_template to extract from same JSON
    - More efficient: 1 MQTT message instead of 6
    - Reduces network traffic and broker load
    - All sensors still properly grouped under device
2025-12-17 Refactor MQTT discovery to follow Home Assistant conventions
    - Separate discovery configs on homeassistant/ and state topics on <hostname>_<entity>/
    - Each entity has unique state topic matching unique_id pattern
    - Add NTP time sync and ISO 8601 timestamps for last_updated sensor
    - Increase MQTT buffer size to 1024 bytes for large discovery messages
    - Add detailed publish failure diagnostics with state codes
    - Add retain flag to all discovery and state publishes
    - Add device_class:timestamp for last_updated sensor
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2025-12-18 fix: resolve macro collision between LEAD_ACID/LIFEPO4 and enum values
    - Rename preprocessor macros from LEAD_ACID/LIFEPO4 to BATTERY_TYPE_LEAD_ACID/BATTERY_TYPE_LIFEPO4 to prevent collision with BatteryChemistry enum values
    - Update all #if/#elif preprocessor checks in battery_config.h, ota_manager.cpp, and test_battery_monitor.cpp
    - Update platformio.ini build flags to use renamed macros
    - Update error message to reference new macro names
    - Update VS Code C++ properties to use new macro names
    This fixes compile errors 'expected an identifier' when using BatteryChemistry::LEAD_ACID and BatteryChemistry::LIFEPO4 in conditional compilation.
    [test_battery_monitor.cpp]
2025-12-21 fix: correct documentation for PlatformIO environments and configurations
    - Remove references to nonexistent esp32dev-leadacid and esp32dev-lifepo4 environments
    - Update build instructions to use esp32dev with BATTERY_TYPE build flags
    - Correct configuration documentation to reference battery_config.h instead of src/main.cpp
    - Fix parameter names to use Config namespace (BATTERY_ADC_PIN, READING_INTERVAL_MS, etc)
    - Correct DEEP_SLEEP.md power calculations (reverse best/worst case years)
    - Update daily consumption from 2.9-5.5 to 2.9-5.6 mAh
    - Apply consistent documentation across README.md, MQTT.md, test/README.md, OTA.md, and .github files
    [test_battery_monitor.cpp]
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2026-01-07 feat: add OTA update display functionality with progress and error handling
    [main.cpp]
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2026-01-10 Fix nosleep command being ignored on first boot
    Problem: When using 'nosleep' command during the 30-second first boot wait period,
    the device would still enter deep sleep despite updating the config.
    Root cause: The deep sleep condition was evaluated before the wait period, so even
    though the user could change config.deepSleepEnabled during the wait, the code had
    already committed to the deep sleep execution path.
    Solution: Re-check config.deepSleepEnabled after the first boot wait period completes.
    If the user disabled deep sleep during the wait, skip deep sleep and use normal delay
    instead.
    This ensures the nosleep command is properly respected when issued during first boot.
    [main.cpp]
2026-01-10 Fix constant reboot loop by using infinite loop when nosleep enabled
    Problem: When deep sleep was disabled with nosleep command, the loop()
    function would finish and restart, causing the device to:
    - Reconnect to WiFi on every iteration
    - Reconnect to MQTT on every iteration
    - Take new readings and publish repeatedly
    - Never properly listen for commands
    Root cause: Arduino's loop() function automatically restarts when it
    reaches the end, triggering all connection logic again.
    Solution: Use an infinite while(true) loop when deep sleep is disabled.
    This keeps the device awake and listening for commands without ever
    allowing loop() to restart. The device only exits this state when:
    - User typ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
    [main.cpp]
2026-05-13 feat: implement appliance relay management with battery protection
    The appliance can now be controlled via MQTT and is automatically forced OFF if the battery voltage falls below a safety threshold. Features include:
    - Hysteresis (cutoff vs recovery thresholds) to prevent relay chatter
    - Persistence of target state in NVS
    - State retention across deep sleep using RTC GPIO hold
    - Home Assistant MQTT Discovery integration as a Switch entity
    [main.cpp]
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2026-06-02 Fix syntax and parsing errors in KiCad PCB layout
    [batterymonitor_pcb.kicad_pcb, batterymonitor_pcb.kicad_sch, bom_jlcpcb.csv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]
2026-06-02 Implement AP63300 buck converter design in PCB and schematic
    [batterymonitor_pcb.kicad_pcb, batterymonitor_pcb.kicad_sch, bom_jlcpcb.csv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]
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2026-06-12 refactor: update wiring guide and BOM files to include new components for USB-C and auto-reset functionality
    [bom_jlcpcb.csv, bom_pcbway.csv]
2026-06-12 Add DC Jack Female component to BOM files for battery monitor PCB
    - Added DC Jack Female (J4) to both bom_jlcpcb.csv and bom_pcbway.csv
    - Updated component details including footprint and manufacturer information
    [batterymonitor_pcb.kicad_pcb, batterymonitor_pcb.kicad_sch, bom_jlcpcb.csv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]
2026-06-18 Implement failover WiFi AP mode and configuration portal
    [main.cpp]
